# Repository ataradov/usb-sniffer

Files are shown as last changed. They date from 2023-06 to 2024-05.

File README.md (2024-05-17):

# Low-cost USB Sniffer (LS/FS/HS) with Wireshark interface

This sniffer can be used standalone from a command line or as a plugin for
[Wireshark](https://www.wireshark.org/) with direct control from the UI.

Either way, the capture is saved in a standard [PcapNG](https://pcapng.com/) format.

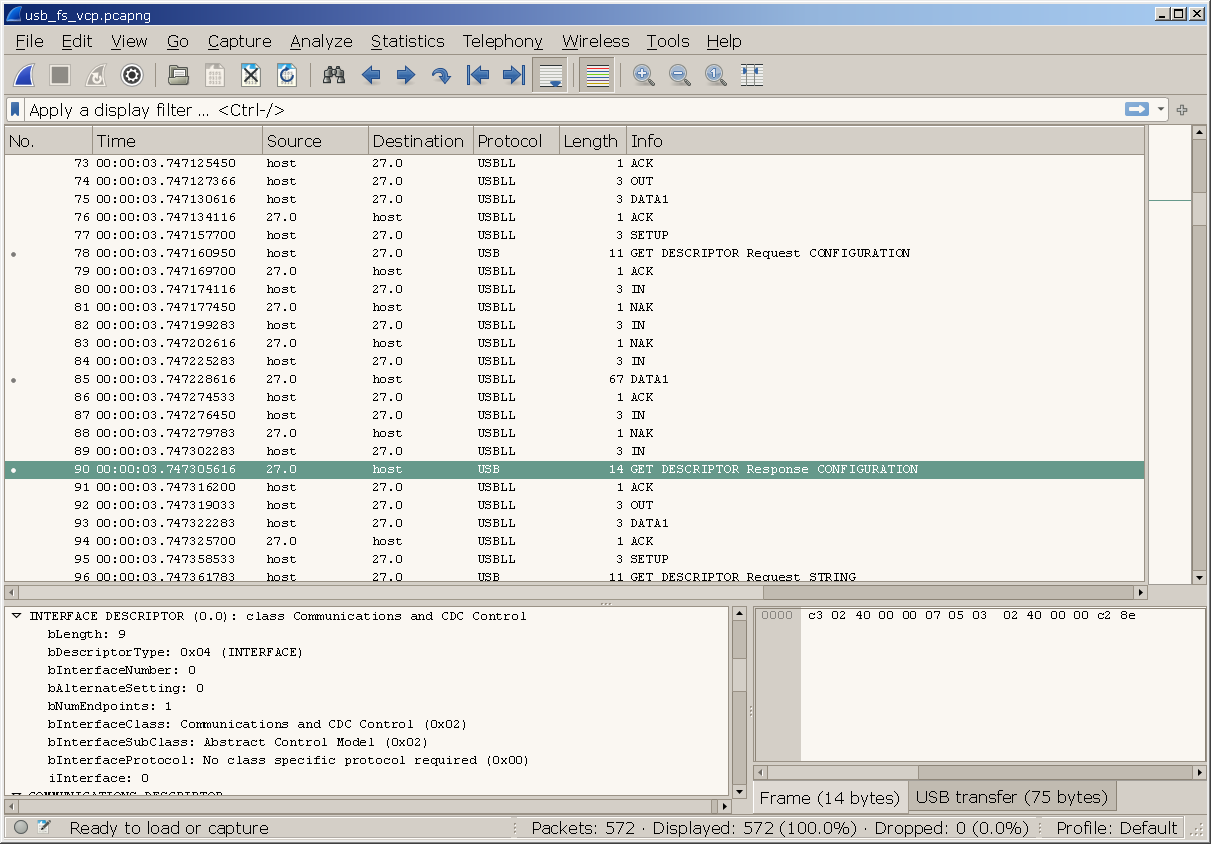
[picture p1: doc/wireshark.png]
Wireshark UI


Here are some example capture files:

 * [Mouse (Low-Speed)](doc/usb_ls_mouse.pcapng)
 * [Virtual COM-Port Adapter (Full-Speed)](doc/usb_fs_vcp.pcapng)
 * [USB Flash Drive (High-Speed)](doc/usb_hs_flash_drive.pcapng)

Note: You will need a recent version of Wireshark (v4.x.x). Older versions may
not be able to decode USB payload, but should still show the raw data.

## Hardware

The sniffer is based around Cypress CY7C68013A MCU, Lattice LCMXO2 FPGA, and
Microchip USB3343 USB PHY.

Prices and availability of ICs vary, but the total BOM should be less than $50.

LCMXO2-2000HC speed grades 5 and 6 were tested and the provided JED file was built
for the speed grade 5, so it should work for both. Speed grade 4 is too slow and
does not meet timing requirements.

Caution: Do not buy CY7C68013A from eBay or AliExpress, they all are either fake
or sketchy in some way. This IC can be quite expensive from regular suppliers,
but [LCSC](https://www.lcsc.com/) is a legitimate supplier and they often have
it at much cheaper prices.

PCBs can be ordered from [OSH Park](https://oshpark.com/shared_projects/avWPFMNs)
or any other PCB manufacturer, [gerber files](bin/usb-sniffer-gerbers.zip) are provided.

There are also STL files for the case.

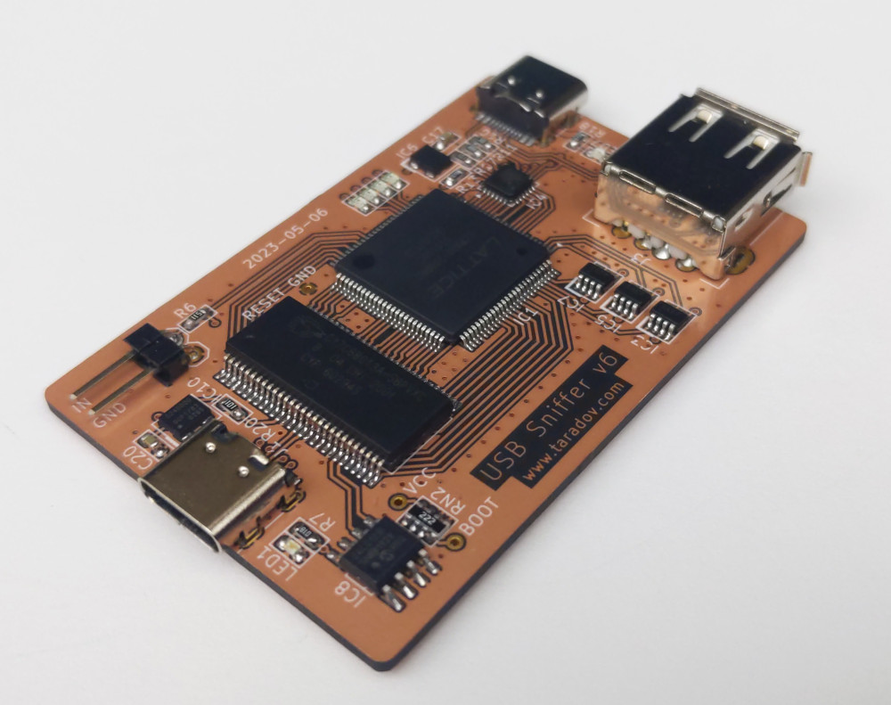
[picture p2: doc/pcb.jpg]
Bare PCB
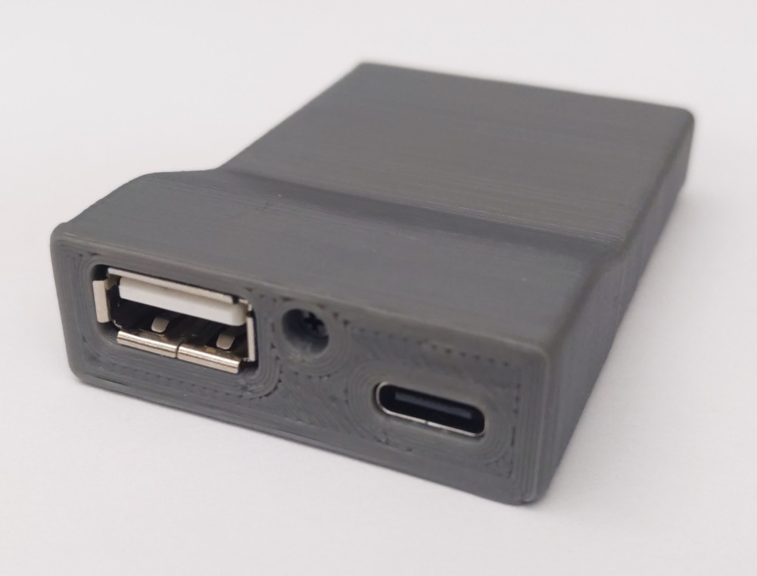
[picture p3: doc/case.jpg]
3D Printed Case
 

## Hardware bring up

This hardware does not require external programmers, both MCU and FPGA are programmed
using a USB interface.

When a board with a blank EEPROM is connected, it would enumerate as an unconfigured
FX2LP device.

Note: on Windows blank FX2LP will enumerate as an unknown USB device. Use supplied
dummy [INF file](bin/blank_fx2lp.inf) as a driver. It will associate blank FX2LP device
with a generic WinUSB driver, so it would be recognized by the tools. Once the firmware
runs, it would supply necessary descripptors automatically.

Note: on Linux copy [90-usb-sniffer.rules](bin/90-usb-sniffer.rules) to /etc/udev/rules.d
to set the permissions to access the device under a regular user.

The first step is to load the firmware into the MCU SRAM:
```
./usb_sniffer --mcu-sram usb_sniffer.bin
```

The device would reset and enumerate as a USB Sniffer with a dummy serial number. After that,
program the EEPROM:
```
./usb_sniffer --mcu-eeprom usb_sniffer.bin
```

After resetting or power cycling, the device would enumerate as a USB Sniffer with a
real serial number. The serial number is derived from the FPGA unique identifier,
so if this step succeeds, it means that FPGA is also functional.

After that program the FPGA flash:
```
./usb_sniffer --fpga-flash usb_sniffer_impl.jed
```

MCU EEPROM can be reprogrammed at any time as long as it is running valid firmware.

In case the firmware gets corrupted, it is possible to run the MCU in the unconfigured
mode by shorting BOOT and VCC test points (located near the EEPROM IC on the board) and
resetting the device. You would need to repeat both steps for programming the MCU
firmware to recover it to the working state.

The functionality and performance of the MCU and FPGA connection can be tested using
the following command:
```
./usb_sniffer --test
```
You should be getting 40-50 MB/s. If the speed is significantly slower, connect the
sniffer directly into the root USB port without intermediate hubs.

It is a good idea to run this test after significant changes to the hardware setup.

## Installation

Pre-built binaries are provided for [Linux](bin/usb_sniffer_linux) and
[Windows](bin/usb_sniffer_win.exe).

To use with Wireshark, copy the file into the extcap plugin directory. Typical
locations are `~/.local/lib/wireshark/extcap` on Linux, and
`C:/Users/<user>/AppData/Roaming/Wireshark/extcap/` on Windows. The exact location is
provided in the `Help -> About Wireshark -> Folders -> Personal Extcap path`.

For Linux, make sure that the binary file has an executable attribute set.

## Usage

After installation, refresh the list of interfaces in Wireshark and you should see
"USB Sniffer" as one of the interfaces:

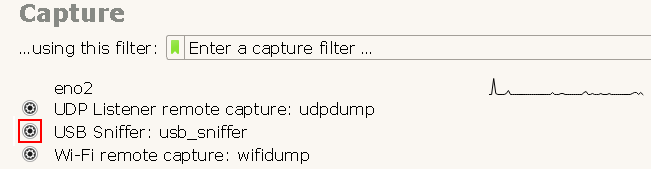
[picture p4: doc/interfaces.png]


The settings icon next to the interface name (highlighted in red) will bring up
the settings dialog:

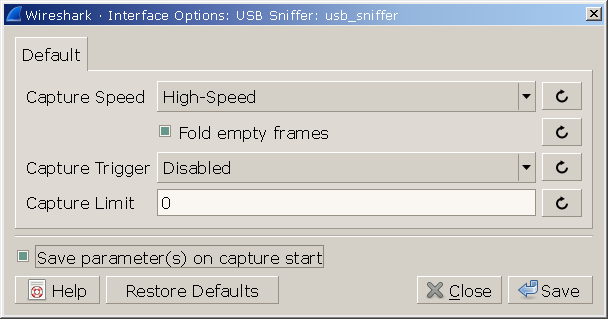
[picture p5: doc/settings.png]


Here you can configure the capture speed, empty frame folding, trigger type and limit
the number of the captured packets (0 for unlimited).

After interface is configured, start and stop the capture as with any other interface.

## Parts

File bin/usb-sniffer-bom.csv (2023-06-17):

Date: | Fri 16 Jun 2023 04:58:26 PM PDT
Tool: | Eeschema 7.0.5-4d25ed1034~172~ubuntu22.04.1
Generator: | /usr/share/kicad/plugins/bom_csv_grouped_by_value.py
Component Count: | 87
Collated Components:
Item | Qty | Reference(s) | Value | LibPart | Footprint | Datasheet | DNP
1 | 24 | C1, C2, C3, C4, C5, C6, C7, C8, C11, C12, C13, C16, C17, C18, C19, C20, C22, C23, C24, C25, C26, C27, C28, C29 | 100nF | ataradov_rlc:C | ataradov_smd:0603
2 | 2 | C9, C10 | 1uF | ataradov_rlc:C | ataradov_smd:0603
3 | 4 | C14, C15, C30, C31 | 2.2uF | ataradov_rlc:C | ataradov_smd:0603
4 | 1 | C21 | 10uF | ataradov_rlc:C | ataradov_smd:0603
5 | 1 | D1 | BAT54S | ataradov_semi:BAT54S | ataradov_ic:SOT-23
6 | 1 | IC1 | LCMXO2-2000HC-5TG100 | ataradov_pld:LCMXO2-100 | ataradov_ic:TQFP-100-0.5mm
7 | 1 | IC2 | MIC5504-3.3v | ataradov_vreg:MIC5504 | ataradov_ic:SOT-23-5
8 | 3 | IC3, IC5, IC7 | MAX9032AKA+T | ataradov_ic:Comp-Dual | ataradov_ic:SOT-23-8
9 | 1 | IC4 | USB3343 | ataradov_ic:USB3343 | ataradov_ic:QFN-24-0.5mm
10 | 1 | IC6 | DSC6101CI2A-026.0000 | ataradov_crystal:DSC61XX-MHz | ataradov_ic:CDFN-4-3.2x2.5mm
11 | 1 | IC8 | 24LC128 | ataradov_ic:I2C-EEPROM | ataradov_ic:SO-8
12 | 1 | IC9 | CY7C68013A-56PVXC | ataradov_mcu:CY7C68013A-56PVXC | ataradov_ic:SSOP-56-0.635mm
13 | 1 | IC10 | DSC6101CI2A-024.0000 | ataradov_crystal:DSC61XX-MHz | ataradov_ic:CDFN-4-3.2x2.5mm
14 | 2 | J1, J2 | USB-C | ataradov_conn:USB-C | ataradov_conn:USB-C
15 | 1 | J3 | USB-A | ataradov_conn:USB-A | ataradov_conn:USB-A-Slots
16 | 1 | J4 | IN | ataradov_conn:Conn-Single | ataradov_conn:Pin-2.54mm
17 | 1 | J5 | GND | ataradov_conn:Conn-Single | ataradov_conn:Pin-2.54mm
18 | 1 | LED1 | Green | ataradov_led:LED | ataradov_smd:0603
19 | 4 | LED2, LED3, LED4, LED5 | Orange | ataradov_led:LED | ataradov_smd:0603
20 | 1 | LED7 | Yellow | ataradov_led:LED | ataradov_smd:0603
21 | 1 | Logo1 | Logo | ataradov_misc:Logo | ataradov_misc:Logo-Small
22 | 4 | R1, R2, R4, R5 | 5.1K | ataradov_rlc:R | ataradov_smd:0603
23 | 7 | R3, R7, R12, R13, R18, R19, R21 | 10K | ataradov_rlc:R | ataradov_smd:0603
24 | 1 | R6 | 510 | ataradov_rlc:R | ataradov_smd:0603
25 | 1 | R10 | 20K | ataradov_rlc:R | ataradov_smd:0603
26 | 1 | R11 | 8.06K | ataradov_rlc:R | ataradov_smd:0603
27 | 1 | R14 | 33K | ataradov_rlc:R | ataradov_smd:0603
28 | 2 | R15, R16 | 4.7K | ataradov_rlc:R | ataradov_smd:0603
29 | 2 | R17, R20 | 100 | ataradov_rlc:R | ataradov_smd:0603
30 | 2 | RN1, RN2 | 2.2K | ataradov_rlc:RN-4 | ataradov_smd:0603x4
31 | 8 | TP1, TP2, TP3, TP4, TP5, TP6, TP7, TP8 |  | ataradov_misc:TestPoint | ataradov_misc:TestPoint-1.27mm-Small
32 | 1 | TP9 | VCC | ataradov_misc:TestPoint | ataradov_misc:TestPoint-1.27mm
33 | 1 | TP10 | BOOT | ataradov_misc:TestPoint | ataradov_misc:TestPoint-1.27mm
34 | 1 | TP11 | RESET | ataradov_misc:TestPoint | ataradov_misc:TestPoint-1.27mm
35 | 1 | TP12 | GND | ataradov_misc:TestPoint | ataradov_misc:TestPoint-1.27mm

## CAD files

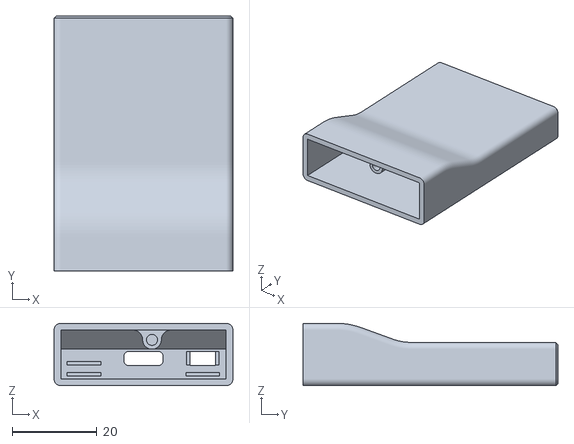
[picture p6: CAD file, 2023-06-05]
hardware/case/usb-sniffer-v6-Case.stl
42.2 x 60.1 x 14.7

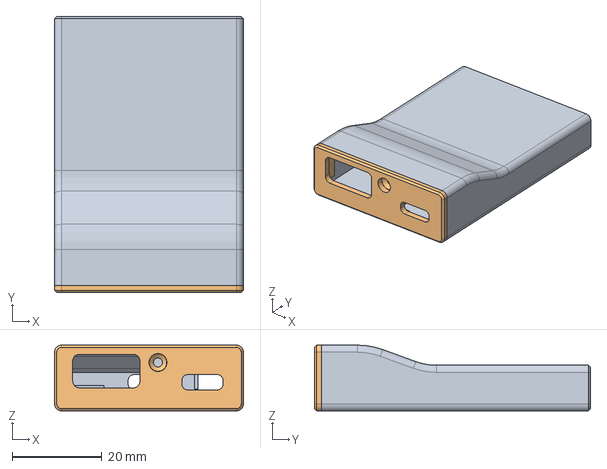
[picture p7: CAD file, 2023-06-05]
hardware/case/usb-sniffer-v6.FCStd
42.2 x 61.7 x 14.7 mm
Case
Cover

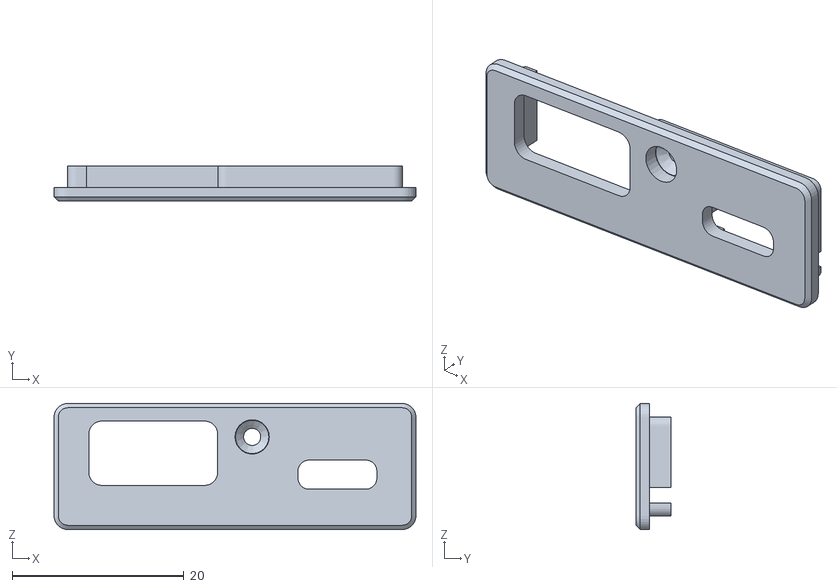
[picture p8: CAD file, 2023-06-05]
hardware/case/usb-sniffer-v6-Cover.stl
42.2 x 4.10 x 14.7

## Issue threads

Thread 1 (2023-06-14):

Request - JLPCB/LCSC BOM & CPL

hanzov69, 2023-06-14:
For the less experienced folks (like myself) out there, would it be possible to provide a BOM & CPL suitable for use with a service like JLCPCB (which is integrated with LCSC and EasyEDA)?

ataradov, 2023-06-14:
Creating BOM should not be that hard, but none of the components have pick points defined. I think most of them are just in the geometric center of the part. LCSC also seems to have most of the major parts. They don't have comparators (well, they have 2 in stock).

I have never ordered board assembly so, I don't know what the requirements are. And I would not be comfortable publishing something I did not test myself. If someone creates the necessary files and tests the whole process with JlcPcb, I can add them to the repo for others to use.

ataradov, 2023-06-14:
But also, if they only assemble boards from EasyEDA and not just random boards, then I don't think there is much we can do. I'm not going to redo the design in EasyEDA for sure.

hanzov69, 2023-06-15:
> I would not be comfortable publishing something I did not test myself
Totally respect that!

> I'm not going to redo the design in EasyEDA for sure.
Naturally. They support pulling in gerber files, so that's not a requirement at all.

EasyEDA/JLCPCB/LCSC are all the same company, so they have an "integrated vertical" type pipeline, but you're not limited to doing it that way. JLCPCB will spin the board just fine with what you've provided, it's only if you want to do assembly with them that you'll need a bom/cpl.

I spent some time after opening this issue, using this plugin ( https://github.com/Bouni/kicad-jlcpcb-tools ) with KiCad I was able to _mostly_ generate a BOM/Placement file for JLCPCB. Biggest thing I ran in to is my own limited knowledge- Looks like LCSC has zero availability on some components and I'm not well enough versed to know what component alternatives (if any) I can use.

I may update the footprints with the exact LCSC part #'s to help along others going down this rabbit hole. If I get something suitable for doing assembly with JLCPCB (and/or EasyEDA formatted), I'll fork the repo and ping (since I respect not wanting to include things you haven't tested).
Thanks for the response!

ataradov, 2023-06-15:
What components are not available? I can help with equivalents. I checked all the major ICs and they were available (although FPGA is much more expensive than on mouser). The only non-generic thing that is not available are comparators. They only had two.

For the clock generators, anything of the specified frequency would work, they don't have to be Microchip parts.

The rest are generic components.

If someone wants to go though the JlcPcb ordering process and test the result, I'm available for help. I'd like people to be able to get the hardware, I just don't have the bandwidth  to do that myself.

sugoku, 2023-06-16:
Hello, I just went through the JLCPCB process myself after finding this and the only things I wouldn't be able to get are the 512 ohm resistor (unless it's supposed to be 5.1K) and the USB3343 (which is out of stock, currently). The USB3343 can be sourced from LCSC but I would have to solder it myself. Also, is there a required size for the EEPROM? I chose a 64Kbit chip.

ataradov, 2023-06-16:
512 Ohm is supposed to be 510 - a very common value. The value of this resistor does not matter, it just provides the current limiting for the trigger input. Anything in the range 0-5 kOhm would work.

64 kBit would work, but I updated the schematic this morning to show 24LC128 - the maximum that can be supported.

Clockwork-Muse, 2024-03-06:
@hanzov69 - Hey, do you have a sample/starting file you can share?  I'm looking at maybe ordering some as well.

Closed 2023-06-15.

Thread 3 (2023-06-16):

IC8 I2C-EEPROM Part Number?

huajijam, 2023-06-16:
Not found in readme and sch

huajijam, 2023-06-16:
found in https://github.com/ataradov/usb-sniffer/discussions/2

using 24lc128 for mine now

ataradov, 2023-06-16:
I've updated the schematic with the EEPROM part name and a full part name for the FPGA.
I've also added note that FPGA speed grade 4 will not work, as it is too slow.

Closed 2023-06-16.

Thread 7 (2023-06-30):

[hardware]IC Obsolete

huajijam, 2023-06-30:
DSC6101CI2A series OSC labled Obsolete in Digikey
and IC6,IC10 are using them
IC6 using 26Mhz only have few stock in Digikey
and the 24Mhz one currently have no stock in Digikey and Mouser

any replacement?I am currently using YXC's OSC and get some problem
in HS device,the sniffer can only detect as FS,and get a lot of error
but with `./usb_sniffer --test` I can get 44-45M/s

huajijam, 2023-06-30:
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

24Mhz: [OT322524MJBA4SL](https://www.lcsc.com/product-detail/Oscillators_Yangxing-Tech-OT322524MJBA4SL_C717686.html) from YXC
26Mhz: ramdom Aliexpress seller claim from YXC [SG-310](https://www.yxc.hk/uploadfiles/2021/11/SG-310.pdf) series and I just not trust it

I bought a new 26Mhz one from Digikey's stock,but it need about 2 week to get in hand,and I just no idea why it can't detect HS mode

huajijam, 2023-06-30:
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

OSC and usb-phy chip image on my board(sry for oversharp img by my phone)

ataradov, 2023-06-30:
Just to double check - have you configured HS mode in the settings? There is autodetection of the speed, but it is mostly for logging and information use. There is no automatic switch. You need to go into the interface settings and configure the speed you expect to see.

I've used 12 MHz version of that Yangxing Tech oscillator from LCSC in a different project and had no issues with them. But I would not trust AliExpress one, especially if there are issues.

huajijam, 2023-06-30:
>

how 2 set speed? in Wireshark? I can't found it

ataradov, 2023-06-30:
In the list of interfaces there is a cog icon next to the name:
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

huajijam, 2023-06-30:
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
it seems work now, but I am getting this error
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

huajijam, 2023-06-30:
btw,will it cause error when using HS mode to capture LS/FS?
if no,why not HS by default

ataradov, 2023-06-30:
This is the issue on the host side. In the data stream there is a toggling bit for each packet used to detect possible corruption. There are many reasons why this may happens, including overflows, bad cables or hubs on the device side. I would try a different cable and a different USB port on a root hub.

You need to capture with the setting that is actually use by the bus. It will not be able to receive the frames at the incorrect speed. There is no identification, speed is a setting. Normally devices negotiate which speed they want to use, but sniffer in general does not know that.

huajijam, 2023-06-30:
>

> This is the issue on the host side. In the data stream there is a toggling bit for each packet used to detect possible corruption. There are many reasons why this may happens, including overflows, bad cables or hubs on the device side. I would try a different cable and a different USB port on a root hub.
>
> You need to capture with the setting that is actually use by the bus. It will not be able to receive the frames at the incorrect speed. There is no identification, speed is a setting. Normally devices negotiate which speed they want to use, but sniffer in general does not know that.

but this error will cause the capture stop and need manually restart,can there be an option to display as a log insteat of killing the capture?

ataradov, 2023-06-30:
No, decoding of the incoming stream depends on the correct tracking of the state. This is how software knows what is a header and what is a data in a continuous stream. There is no way to recover if there was de-synchronization.

ataradov, 2023-06-30:
Note that this is not an overflow on the capture side, which would cause frames to be dropped and corresponding log message to be issued.

This is an error on the host side, which should not happen really. If it does, it means that host side communication is not reliable for some reason.

If you can't make it work with a different cable and a different USB port, I can add a bit of debug logic and we can try to debug this if you can reliably reproduce the issue. I've only seen it a couple times when working tough a dodgy hub.

huajijam, 2023-06-30:
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

I can reproduce it a lot of time,I make it bcz my desktop usb3.0 hub sometimes will give me a code 43 or code 10 in some usb 2.0 device and only 2.0,I want to check what happened
but it seems like when I plug it in sniffer,it will fix this problem(wtf)
I am currently using hub from my dell monitor, and I can reproduce it by plug in a bad usb device
as ur said, it came from error in host,but I am using a different hub for my target, and it will still error

both desktop hub and monitor hub are plug into pc's back usb3.0

ataradov, 2023-06-30:
I don't understand your setup. But using hubs for the sniffer host connection is prone to cause errors like this. Hubs sometimes are bad at handling a lot of traffic. It is far better to use direct connection for the sniffer itself.

As for fixing the errors - I don't know why that wold be the case. In theory host would not be able to tell if there is a sniffer in-between.

huajijam, 2023-06-30:
> I don't understand your setup. But using hubs for the sniffer host connection is prone to cause errors like this. Hubs sometimes are bad at handling a lot of traffic. It is far better to use direct connection for the sniffer itself.
>
> As for fixing the errors - I don't know why that wold be the case. In theory host would not be able to tell if there is a sniffer in-between.

rear usb3.0 → desktop 3.0hub(have issues) → target type-c port
rear usb3.0 → dell monitor 3.0hub → host type-c port

monitor's hub should be fine, as it will work if the desktop does not

maybe some debugging logic will make it easier to find out where the problem is

ataradov, 2023-06-30:
I will add some logic a bit later, not sure how helpful it would be though.

But in the mean time I would try to avoid hubs for the host connection.

ataradov, 2023-07-01:
I've added printing out of the header along with the error message. This in combination with the last frame should show a bit more information on what is going on. I don't know if that would be sufficient to fully debug this specific case though.

The error window will no longer show up, but the capture would stop on errors like this. The last messages in the log would be the diagnostic info.

Closed 2023-07-01.

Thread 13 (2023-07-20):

I used 4TG100C, Transfer rate:  0.00 MB/s

vgegok, 2023-07-20:
I used diamonds to regenerate the jet file of 4TG100C, and initially everything was normal. However, when I tried to measure the speed, I got a result of 0 on Windows, and Linux would directly report an error.

# Windows:

```
PS E:\USB\usb-sniffer-main\usb-sniffer-main\bin> .\usb_sniffer_win.exe --mcu-sram .\usb_sniffer.bin
Uploading 3187 bytes into the FX2LP SRAM
...done

PS E:\USB\usb-sniffer-main\usb-sniffer-main\bin> .\usb_sniffer_win.exe --mcu-eeprom .\usb_sniffer.bin
Programming 3187 bytes into the FX2LP EEPROM (SN: 443602XXXXXXXX)
...done

PS E:\USB\usb-sniffer-main\usb-sniffer-main\bin> .\usb_sniffer_win.exe --fpga-flash ..\fpga\impl\usb_sniffer_impl.jed
Programming FPGA flash
Erasing flash
Programming configuration data .....
Verifying configuration data
Programming and verifying Feature Row
Programming and verifying FEABITS
Exiting programming mode
...done

PS E:\USB\usb-sniffer-main\usb-sniffer-main\bin> .\usb_sniffer_win.exe --test
Starting speed test
Transfer rate:  0.00 MB/s
Transfer rate:  0.00 MB/s
Transfer rate:  0.00 MB/s
Transfer rate:  0.00 MB/s
Transfer rate:  0.00 MB/s
Transfer rate:  0.00 MB/s
Transfer rate:  0.00 MB/s
Transfer rate:  0.00 MB/s
Transfer rate:  0.00 MB/s
Transfer rate:  0.00 MB/s
```

# Ubuntu 20.04:

```
$ ./usb_sniffer --test
Starting speed test
Error: usb_capture_callback(): 4
```

ataradov, 2023-07-20:
Callback status 4 is LIBUSB_TRANSFER_STALL. This is strange,because FX2LP should not stall on hardware endpoints. What was the source for the FX2LP device?

From the FPGA side, I would verify that PHY oscillator is running at 26 MHz and that there is 60 MHz clock on the output from the PHY.

Speed grade 4 device does not meet timing requirements, so you should see warnings about that in the log. It might work at room temperature, I guess.

vgegok, 2023-07-20:
Your answer gave me a hint, I know why. Since the 8.06K resistor has not yet arrived, I did not weld it!

I haven't read your code carefully yet.
At first, I didn't know which clock source the FPGA uses. I thought that the USB3343 wouldn't affect speed testing if it didn't work.
Now I know that the FPGA clock is provided by USB3343 (60MHz), so when conducting speed testing, the 8.06K resistor must be soldered.
Looking forward to receiving it!

Thank you again for your answer!

---- Replied Message ----
| From | Alex ***@***.***> |
| Date | 07/20/2023 23:12 |
| To | ataradov/usb-sniffer ***@***.***> |
| Cc | vgegok ***@***.***>,
Author ***@***.***> |
| Subject | Re: [ataradov/usb-sniffer] I used 4TG100C, Transfer rate: 0.00 MB/s (Issue #13) |

Callback status 4 is LIBUSB_TRANSFER_STALL. This is strange,because FX2LP should not stall on hardware endpoints. What was the source for the FX2LP device?

From the FPGA side, I would verify that PHY oscillator is running at 26 MHz and that there is 60 MHz clock on the output from the PHY.

Speed grade 4 device does not meet timing requirements, so you should see warnings about that in the log. It might work at room temperature, I guess.

—
Reply to this email directly, view it on GitHub, or unsubscribe.
You are receiving this because you authored the thread.Message ID: ***@***.***>

vgegok, 2023-07-21:
I soldered an 8.2K resistor at position R11, and now the test is working properly!

At first, I tested the clock signals of 26MHz (PIN21) and 60MHz (PIN2) with an oscilloscope and found that 26MHz was normal, but there was no 60MHz clock. After I welded the resistor, everything was normal.

As I said, this bias resistor will affect the operation of USB3343, resulting in the inability to output a 60MHz clock signal.

```
 .\usb_sniffer_win.exe --test
Starting speed test
Transfer rate: 48.57 MB/s
Transfer rate: 48.96 MB/s
Transfer rate: 48.71 MB/s
Transfer rate: 48.81 MB/s
Transfer rate: 48.86 MB/s
Transfer rate: 48.81 MB/s
Transfer rate: 48.81 MB/s
Transfer rate: 48.81 MB/s
Transfer rate: 48.81 MB/s
Transfer rate: 48.76 MB/s
Transfer rate: 48.86 MB/s
Transfer rate: 48.91 MB/s
Transfer rate: 48.71 MB/s
Transfer rate: 48.81 MB/s
Transfer rate: 48.81 MB/s
Transfer rate: 48.76 MB/s
Transfer rate: 48.91 MB/s
Transfer rate: 48.76 MB/s
Transfer rate: 48.96 MB/s
Transfer rate: 48.76 MB/s
Transfer rate: 48.86 MB/s
Transfer rate: 48.86 MB/s
Transfer rate: 48.76 MB/s
Transfer rate: 48.81 MB/s
Transfer rate: 48.76 MB/s
Transfer rate: 48.86 MB/s
Transfer rate: 48.81 MB/s
Transfer rate: 48.91 MB/s
Transfer rate: 48.91 MB/s
Transfer rate: 48.67 MB/s
Transfer rate: 48.86 MB/s
Transfer rate: 48.76 MB/s
Transfer rate: 48.86 MB/s
Transfer rate: 48.76 MB/s
Transfer rate: 48.86 MB/s
Transfer rate: 48.81 MB/s
Transfer rate: 48.81 MB/s
Transfer rate: 48.86 MB/s
Transfer rate: 48.91 MB/s
Transfer rate: 48.81 MB/s
Transfer rate: 48.91 MB/s
Transfer rate: 48.86 MB/s
Transfer rate: 48.76 MB/s
Transfer rate: 48.86 MB/s
Transfer rate: 48.81 MB/s
Transfer rate: 48.86 MB/s
Transfer rate: 48.96 MB/s
Transfer rate: 48.71 MB/s
Transfer rate: 48.91 MB/s
Transfer rate: 48.91 MB/s
Transfer rate: 48.67 MB/s
Transfer rate: 48.91 MB/s
Transfer rate: 48.81 MB/s
Transfer rate: 48.96 MB/s
Transfer rate: 48.71 MB/s
Transfer rate: 48.91 MB/s
Transfer rate: 48.81 MB/s
Transfer rate: 48.86 MB/s
Transfer rate: 48.91 MB/s
Transfer rate: 48.76 MB/s
Transfer rate: 48.91 MB/s
Transfer rate: 48.81 MB/s
Transfer rate: 48.86 MB/s
Transfer rate: 48.81 MB/s
Transfer rate: 48.76 MB/s
Transfer rate: 48.67 MB/s
Transfer rate: 48.76 MB/s
Transfer rate: 48.81 MB/s
Transfer rate: 48.62 MB/s
Transfer rate: 48.71 MB/s
Transfer rate: 48.81 MB/s
Transfer rate: 48.62 MB/s
Transfer rate: 48.71 MB/s
```

vgegok, 2023-07-21:
@ataradov, Thank you.
I will close this issues.

ataradov, 2023-07-21:
Good to know that it actually does not even start without that resistor.

Closed 2023-07-21.

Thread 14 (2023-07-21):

Error: libusb_bulk_transfer(): LIBUSB_ERROR_OVERFLOW, usb_capture_callback(): 6

croofec, 2023-07-21:
I can't run a speed test after successfully installing. The connection between the USB and the computer works fine, I can't sniff
Current usblib version: libusb-1.0.26, all parts from mouser.

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

Hardware or software issue?

ataradov, 2023-07-21:
This may be related to a recent change.

Build the binary from the source and change TRANSFER_COUNT in usb.c from 16 to 8 or even 4.

If this helps, please check what is the maximum value that causes the issue.

I'm not sure what defines how many transfers libusb would accept at the time. It appears to be system dependent.

croofec, 2023-07-24:
Changing the parameter had no effect even when I set it to 1.  I started debugging the software and always the bulk transfer buffer returned the size of 64 which is smaller than the size of 512. This could not cause overflow.  But in the dmesg:

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

I changed the slot from USB2.0 to USB3.0 and it works :D

ataradov, 2023-07-24:
Ok, yes, I don't do anything to accommodate the case when it enumerates as a Full-Speed device.

HS mode is USB 2.0, so there must be something wrong with that specific port or your cables. It looks like it tried to enumerate as HS device, but could not.

Closed 2023-07-24.

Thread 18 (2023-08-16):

Only syslog entries

brunopp, 2023-08-16:
I just assembled the board and followed the instructions to flash the device and get the desired speed of 40-50 MB/s - all good.

When connecting a usb device (mouse -> full speed) to the port I get data in wireshark, but no usb data, I only get "Syslog" entries. I have also tried different usb drives at high speed. Also the log stops after about about 1000 entries (only for high speed). I have selected the correct Capture Speed in wireshark.

All the devices I have tried works when connected through the usb-sniffer board.

I have also noticed I get VBUS OFF in one of the first entries as opposed to VBUS ON the examples under /doc.

Logs: [wireshark.zip](https://github.com/ataradov/usb-sniffer/files/12356815/wireshark.zip)

Also only two LED's light up (LED 1 and LED 7), are the other LED supposed to light up?

As for the BOM I could not find the exact oscillators, but found others within 50 ppm:
[DSC1001CI2-024.0000](https://www.mouser.dk/ProductDetail/998-1001CI2-024.0000)
[DSC1001CI5-026.0000](https://www.mouser.dk/ProductDetail/998-1001CI5-026.0000)

ataradov, 2023-08-16:
This looks like there is some issue with the USB PHY.

First of all, check that the soldering looks ok. Attach magnified pictures, if you can.

Then check that you have 26 MHz on the output of the oscillator and 60 MHz on the output of the PHY (CLKOUT pin).

If you look at the HS log, you will see a lot of JK toggles, which start with "[singel]" and continue with "[both]". This is a normal part of the HS speed negotiation. What is wrong here is that they are supposed to be ~50 us in duration and in your case they are 20 us. This looks like incorrect clock is being used.

ataradov, 2023-08-16:
And LEDs are fine, the 4 other LEDs are there for debugging and are not used in the release version.

brunopp, 2023-08-16:
The oscillator (IC6) is outputting 26 MHz. But I'm not getting 60 MHz on the USB (IC4) on pin 2, but 26 MHz as well as shown below:

[Circuit](https://github.com/ataradov/usb-sniffer/assets/6736551/7c2ae64c-b328-4abf-bd88-24536002b0bd)
[Oscilloscope (IC4, pin 2)](https://github.com/ataradov/usb-sniffer/assets/6736551/7dd35c75-c68a-4e8f-8072-c623b71c555f)

Which is odd? The according to the [datasheet](https://eu.mouser.com/ProductDetail/Microchip-Technology/USB3343-CP-TR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) it should output 60 MHz.

ataradov, 2023-08-16:
What is the value of the resistor on the pin 19 (RBIAS). It is critical that it is 8.06 kOhm +/-5%.

Neither B22 or 822 seem to match that value, but SMD codes are all over the place. So check the value with a multimeter.

brunopp, 2023-08-16:
It isn't clear how important exact values are from the BOM, so I just used the closest I had 8.2kOhm +-1%. I tried to solder 470k in parallel with 8.02k getting 8.06k measured (isolated from the circuit), but no luck.

Are there other critical resistor values in the circuit?

ataradov, 2023-08-16:
If the value is specified with that accuracy, it must be important. If 8.2 kOhm worked, it would have been on the schematic, it is not like I'm adding random values for fun.

No other values are critical as far as I know, so I would look for possible shorts.

Or may be reflow or change the PHY and see if that helps. I have never seen it output the input clock directly. Usually it is either nothing if the resistor is missing entirely, or 60 MHz.

ataradov, 2023-08-16:
And check for other voltages too, like VDD18 should be at 1.8 as supplied by the internal voltage regulator. If it is not at 1.8, check that C15 is placed and has correct value.

ataradov, 2023-08-16:
The JK chirp at the beginning still looks messy. It was way better in your original capture. It should be clean J/K toggles at ~50 us internal.

Double check your resistor divider ladder for the compactors.

brunopp, 2023-08-16:
Strange, I didn't reflow the backside where the resistor dividers are placed nor the comparators on the top side.

ataradov, 2023-08-16:
It feels like something is not soldered fully. There should be no random line state changes in the middle of the data.

I would carefully check all the comparators and related tracks pins. May be measure reference voltage levels on the resistive ladder and make sure that they are correct.

brunopp, 2023-08-16:
You are talking about the high speed log? Specifically: Syslog Line state: undefined? For example line no. 7715 and 8893.

I'll try some additional reflow.

ataradov, 2023-08-16:
Yes. Look at your original HS log. At the beginning you can see that there are K/J state pairs, first [single] and then [both]. Their timing is not correct because it was running at 26 MHz, but the order is fine.

The time in the original log is 21 us, but the actual real time is (60/26) * 21 us = 48.5 us. This is the time you should expect.

You should see the same in the new log. There should not be undefined states. It is fine if there are some due to transient, but they should not be long.

brunopp, 2023-08-16:
Reflowing the comparators and divider resistors seemed to have worked, I find no undefined states (except a little bit at the beginning, which should be due to transient as you mentioned).

Logs: [wireshark - after reflow.zip](https://github.com/ataradov/usb-sniffer/files/12364141/wireshark.-.after.reflow.zip)

ataradov, 2023-08-16:
Yep, this is the correct result.

Closed 2023-08-16.

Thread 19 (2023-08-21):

Issue with high speed devices

bkerler, 2023-08-21:
Hi,

I've built two boards and both works fine with low-speed and full-speed devices. However if I try to connect any high-speed device such as a android smartphone, the device cannot be enumerated (neither adb, fastboot nor serial). I checked the oscillators and they deliver 24 mhz and 26 mhz as expected, 60 mhz at the usb_clk of the usb3343. Voltage measured at vdd18 is 1.78V. Doesn't matter if the capture is on or not, the usb enumeration fails all the time and the device isn't detected.

Any ideas why the usb enumeration fails ?

[usblog.zip](https://github.com/ataradov/usb-sniffer/files/12402017/usblog.zip)

ataradov, 2023-08-21:
Try different USB port on the PC and don't use hubs for the target device. Also make sure that the board are clean from flux contamination. Some fluxes are mildly conductive and may cause issues at high frequencies.

 The logs looks similar to another issue and there the problem was resolved by using a different USB port.

Also, just for statistics, what PC/motherboard you are using?

bkerler, 2023-08-21:
Ok, it seems I've figured out what the issue is on high speed.

SW-Side:
1. Capture has to run, otherwise fails as well
2. Always connect the device port first (USB-A), then the sniffer port (USB-C), otherwise it fails.

HW-Side:
On the host side (host -> sniffer) anything (usb 2.0/usb 3.0/usb 3.1) except usb 4.0 hub works.
On the client side (sniffer -> host) only usb 2.0 hub works (here: Realtek Semiconductor Corp. RTS5411 Hub)

I've tested it on two amd systems (usb 3.1 regular pc and usb 4.0 laptop lenovo z16).

So I'm still wondering if the usb3343 doesn't like amd hubs or if it's an issue with the two boards that I've got (both were fully pnp by jlcpcb except the usb3343). On the optical side using microscope I couldn't see any potential issue.

bkerler, 2023-08-21:
Could it be that the cc1 and cc2 lines might cause issues ?

ataradov, 2023-08-21:
Capture running or not is a purely logical thing, it does not affect the transceiver state, so it should not matter.
Order of device connection also should not matter. Something is just marginal in that setup.

It is better to avoid hubs for performance reasons, especially for the sniffer itself. Hubs decrease available bandwidth quite a bit. What does speed test say, BTW?

A sniffer has to break the signal lines in order to tap into them, so there will be some loss of integrity, plus transceiver and comparators  add extra load. Even if not significant, it is not zero, which may push marginal configurations into unstable mode.

It is strange to me that in your logs transceiver can't receive any frames at all, even broken ones. So, something breaks to the point where even sync sequence is damaged.

How would CCx lines cause the issue? The sniffer has required resistors on the USB-C side. In that respect electrically it is no different than any Type-C to Type-A cable.

bkerler, 2023-08-21:
No, cc1 and cc2 can be ruled out as both usb-c are connected via the same resistors. So seems clearly the usb3343 or IC6 is causing the issues. I had to replace the IC6 with this chip : [3N26000G33YC](https://jlcpcb.com/partdetail/247517-3N26000G33YC/C252342), just to rule that out, could this one cause the issues ?

ataradov, 2023-08-21:
Although no, there are SOF and Get Device Descriptor requests from the host. The device does not respond, so it is not the sniffer that can't see the frames. You can see the host retries many times before giving up. So, it also can't see them. It is Android phone that can't seemingly interpret them after whatever minor loss is introduced by the sniffer.

Try with different devices, including simple stuff like USB flash drives. This may be just Android phone issue and it being marginal.

+/- 30 ppm generator should be good enough.

bkerler, 2023-08-21:
Tried with several high speed devices including usb sticks, they all seem to have the same issues on enumeration, only a specific hub setup (usb 2.0 on the device side) does work. Without the sniffer (or with beagle480 sniffer instead), everything seems to work fine, so it has to be something the sniffer introduces. I saw that the issue #7 seems to have had the same problems.

Speed test says 44.90 MB/s.

bkerler, 2023-08-21:
Seems the issue is the usb3343, found an answer in a forum :
[errata](http://ww1.microchip.com/downloads/en/DeviceDoc/80000645A.pdf)

[forum_message](https://community.st.com/t5/embedded-software-mcus/stm32f2-f4-problems-with-various-ulpi-usb-phys/m-p/554240)

ataradov, 2023-08-21:
I have no idea what it could be. I doubt it is the transceiver. If anything, it would be the comparators.

I have not done significant testing with hubs, since the plan was always to connect as close to the root hub as possible.

This errata has nothing to do with this, since PHY here is fully passive. The whole sniffing tap should not introduce significant distortion between the devices.

The most likely issue is signal integrity caused by discontinuity in the path and multiple taps going the comparators and the transceiver.

bkerler, 2023-08-21:
Ok, will try to remove the comparators then and retest the behavior.

ataradov, 2023-08-21:
Also, RTS5411 sees to support USB3.2 Gen1, so it is not just UBS2.0 hub. And in either case, none of them should care, since we are clearly only using USB2.0 part.

ataradov, 2023-08-21:
Another possible factor - the cables. I just tried to experiment with hubs. The only type of hubs I have is this https://www.amazon.com/gp/product/B00JX1ZS5O .  I chained two of them just to add extra challenge.

I used Pixel 3a as a target to get as close to your setup as possible.

With the first test I used one good USB cable and one random Chinese (with silicone cable, so super flexible). With that setup I had all sorts of issues. Not missing packets entirely, but CRC issues and random packet drops, device failed to connect half the time.

I replaced the Chinese cable with a good one and all issues went away, it works perfectly every time though both hubs.

The "good" cables I use are  https://www.amazon.com/gp/product/B01GGKYR2O/ , which perform very well.

For the flexible cables - I suspected they are not the best, but I really like how flexible they are. And with that cable and direct connection (no sniffer), the phone also works.

So, obviously sniffer adds some distortion, which is to be expected. But it only affects the result with bad USB cables. The same setup with a cable swapped works just fine.

ataradov, 2023-08-21:
And this is something to keep in mind too - with the sniffer you have double the cable length. Even if the sniffer is ideal and does not cause additional distortion, increasing the cable length may cause issues on its own.

wocard2, 2023-08-29:
Could adding one (or two) TUSB216 or TUSB217 to the design help with bad and/or long cables?

ataradov, 2023-08-29:
Impossible to tell without having proper measurement equipment and understanding what any of the issues are. And I don't have such equipment.

I don't consider it to be a serious issue. Using good cables is a good idea no matter what.

bkerler, 2023-11-26:
I did more tests and it seems that the sniffer works with android phones with microusb pretty well but has issues with smartphones  with usb-c port (even though these only have usb 2 in fact). So far no difference with the comparators removed / replaced

LiHangBing, 2025-04-17:
I find the same questions,
I use a "Cypress FX2LP No EEPROM Device" device,
first, I connect listen port and device port, and then plug host port to a usb port which belong to the same root hub (each port is usb 2.0), It  emulate fail .

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

then I choose a better cable for host connect, and plug the host cable to annother root hub (usb 3.0), it works!

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

Maybe because of plugging two usb cables to a same hub and it works only at usb2.0 doesn't work.

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

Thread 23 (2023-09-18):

Issue with high speed devices

aozima, 2023-09-18:
Hi,

I've built 5pcs boards, works fine with full-speed devices.

I try to connect any high-speed device, e.g: Udisk or Card Reader。

The PC can enumeration  and  read/write disk, but Wireshark can't capture data.

test hardware

```
$ sudo ./usb_sniffer_linux --test
Starting speed test
Transfer rate: 48.05 MB/s
Transfer rate: 48.26 MB/s
Transfer rate: 48.25 MB/s
Transfer rate: 48.12 MB/s
```

aozima, 2023-09-18:
case 1:
only `Detected speed: Full-Speed`

```
Protocol	Length	 	Info
Syslog	27		USB PHY error
USBLL	1		Invalid Packet ID (0xff)
Syslog	39		Line state: J (583.00 ns)
Syslog	40		Detected speed: Full-Speed
Syslog	41		Line state: SE0 (257.70 us)
Syslog	46		Line state: K [single] (5.08 ms)
Syslog	40		Line state: SE0 (25.35 us)
Syslog	47		Line state: K [single] (49.00 us)
Syslog	47		Line state: J [single] (49.00 us)
```

ataradov, 2023-09-18:
Did you configure the high-speed mode in the interface settings? The detection message is just information, it does not actually change the capture speed.

Closed 2023-09-18.

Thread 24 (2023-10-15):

LCMXO2-2000HC-5TG100C

imayka, 2023-10-15:
Hello. Can I replace LCMXO2-2000HC-5TG100C with LCMXO2-2000HC-5TG100I ? LCSC has both of them but prices are 65$ vs 15$ correspondingly. Should I modify or recompile FPGA project if yes? Thank you!

imayka, 2023-10-15:
Ok, so the difference between Industrial or Commercial is only Operating Temperature. But will firmware prepared for C device work with I device without modification (recompiling)?

ataradov, 2023-10-15:
You can use any temperature variant without changing the binary.

ataradov, 2023-10-15:
For me it shows both out of stock, but industrial is available pre-order, so it has the real updated price. Commercial one still has outrageous shortage price listed.

imayka, 2023-10-15:
> You can use any temperature variant without changing the binary.

Thank you!

Closed 2023-10-15.

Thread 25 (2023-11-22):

The on-board LEDS

fizzyade, 2023-11-22:
It would be useful to have through hole pad options for the on board LEDS, once the PCB is in an enclosure the LED's are no longer visible, I can obviously modify the hardware to provide these PTH holes, it's a 2 minute job, but I figure that it might be a useful thing for other people since an enclosure protects the PCB, so I figured I'd ask here to see if threres any interest in providing these pads in the origin repo.  I could solder coil wire directly to the SMD pads, but my concern there would be that it would be relatively easy to rip the pad off during later disassembly if I forget about it.

The pictures here show my case design, I could put the leds on a surface on the main body or on the end caps.

Many thanks for the brilliant project!

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

ataradov, 2023-11-22:
For this design, I don't really want to do anything with the LEDs. In my case I relied on the gray plastic being transparent, and it works well enough. LEDs here are not all that useful anyway, and I don't want to create a hardware revision just for that.

I hate working with through hole LEDs, so I avoid them in my designs, but since I'm also making 3D printed cases, it does become an issue. And I'm trying to figure out how to address this. But my experiments are focused on making clam shell cases and printing in holes for the light pipes or something like this.

fizzyade, 2023-11-23:
No problem, I figured that since they weren’t there then that would be the answer!  I’ll just modify it myself (thanks for the open source design!)

It wasn’t so much about actually mounting PTH LED’s directly onto the board, it was purely just providing a PTH hole so that the location of the LED's don’t need to be tied to a specific location on the PCB, with a test point the wires could just as easily connect to a daughter board that has a bunch of SMD LED’s arranged is a coherent order.

It’s just a sanity check for me since my USB cables often work themselves loose on my laptop, so looking at the LED’s is an easy confirmation that at least power is getting to the device from the host.

Adrian
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

KarlK90, 2024-02-18:
@fizzyade Hi Adrian, I like your take on the case very much, would you mind sharing the case files?

fizzyade, 2024-02-18:
Yeah no problem, I will upload them later to printables, remind me tomorrow if I haven't replied with the link.

fizzyade, 2024-02-18:
> @fizzyade Hi Adrian, I like your take on the case very much. ~would you mind sharing the case files~? Already found it here https://www.printables.com/model/657228 - thanks for sharing.

Yeah, I couldn't log in earlier and when I just managed to get in I realised I'd already shared it!

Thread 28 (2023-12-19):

USB high speed capture lost some packets

genknife, 2023-12-19:
Hi,
I captured a device like usb printer with high speed. If I print one page with simple content, it is OK. But if I print one page with complex content，some packet lost, And some syslog message said "Hardware buffer overflow".
I have also done a transfer rate test, result is about 48MB/s.
USB 2.0 high speed can mostly reach 60MB/s, but README recommend  transfer rate 40~50MB/s. If printer usb high speed transfer rate reach 60MB/s, I will always lost some packets?

ataradov, 2023-12-19:
Maximum theoretical USB HS transfer rate is ~53 MB/s after physical protocol overhead. But with the way practical host schedule transfers, you get 48-49 MB/s as a maximum practical transfer rate. So, the printer is also not going to be faster than 48 MB/s. But the sniffer is adding its own overhead with timestamp information and other information about the packets, so it will always be slower.

Some lost frames are normal. It is impossible to capture a lot of traffic on one interface going at full speed. This is a debugging tool, it is not meant to capture absolutely everything at once.

That being said, there are a couple things you can check:
1. Do a speed test while printer is printing. See if the speed drops. It may drop depending on the root hub port mapping. You may be able to get better results by using different set of USB ports.
2. This may be a slowness of Wireshark and the pipe interface (it is known to be slow on Windows). You can capture directly to the file from the command line and then open the final captured file in Wireshark. This way you will not be limited by the Wireshark UI trying to display all those frames in run-time.

tencyrat, 2023-12-22:
0x012ba043

tencyrat, 2023-12-22:
Error: incorrect FPGA IDCODE (0x012ba043)
so i should chang fpga.c to 0x012ba043?anything i need to change?

tencyrat, 2023-12-22:
same issues,i replace it with LCMXO2-2000HC-6TG100C,could you offer me 6TG100C jed files?thanks!

tencyrat, 2023-12-22:
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

same issues,i replace it with LCMXO2-2000HC-6TG100C,could you offer me 6TG100C jed files?thanks!

ataradov, 2023-12-22:
Replacing with a different FPGA will not do anything for lost packets. The same JED file will work for all speed grades.

In the deleted comments you mention your ID CODE is 0x012ba043. This ID CODE belongs to LCMXO2-1200HC. This will not work, you need 2000HC device.

tencyrat, 2023-12-23:
First of all, thanks for your reply. I may have bought a fake chip. The silk of the chip is LCMXO2-2000HC-6TG100C.but the ID CODE is 0x012ba043.

ataradov, 2023-12-23:
This is a strange thing to fake, since it will be discovered right away. Those devices have different bit-stream size, so programming would not work even if you change the ID.

Can you show pictures of the device? I have never seen them faked, so I wonder how it compares to the real device.

tencyrat, 2023-12-25:
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

when i patch the id code,fpga burning pass,but it does not work,speed test is 0MB/s.
i use microscope to take photo.5TG is Genuine,6TG is fake.
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
i purchase it from taobao.com so avoid it!

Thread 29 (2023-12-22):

We need adaptive communication speed!

Antecer, 2023-12-22:
My device is compatible with HS and FS communication. It works in HS by default. When the HS handshake fails, it will automatically switch to the FS handshake.
I hope usb-sniffer can work in HS mode by default and be backward compatible with FS communication capture.
If working at a fixed communication speed, it will not meet my work needs in this case.

ataradov, 2023-12-22:
There is no way to automatically switch the speed. First of all, there is no reliable way of doing this. The speed negotiation is a process that can be interpreted one way by the tool and the other way by the devices.

And the more important thing - it is no the goal of this tool. This is a debugging tool that is supposed to be used in a controlled environment.

When debugging a device that is capable of operating at a multiple speeds, debug operation at each speed separately with a host that you know can do HS or FS. This way you know what speed is expected to be negotiated and you can set it up ahead of time.

If you need to understand why the speed detection failed, you can use either speed, since all of that happens with line-state changes, which are the same regardless of the configured speed.

If you can describe a legitimate scenario where this is necessary, I'll be glad to hear it. But I pretty much guarantee that I won't do auto speed switch.

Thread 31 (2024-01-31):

Help flashing to eeprom

anujdeshpande, 2024-01-31:
Hey @ataradov - I am trying to assemble this, but running into issues with the FPGA IDCODE. Is this something you have seen before? Any tips on what could be the issue?

```
$ ./usb_sniffer_linux --mcu-sram usb_sniffer.bin
Uploading 3187 bytes into the FX2LP SRAM
...done
$ ./usb_sniffer_linux  --mcu-eeprom usb_sniffer.bin
Error: incorrect FPGA IDCODE (0x00000000)
$
```
On kernel.log, I see

```
Jan 31 13:04:14 mbradmin-System-Product-Name kernel: [938797.213555] usb 1-6: new high-speed USB device number 25 using xhci_hcd
Jan 31 13:04:15 mbradmin-System-Product-Name kernel: [938797.361730] usb 1-6: New USB device found, idVendor=04b4, idProduct=8613, bcdDevice=a0.01
Jan 31 13:04:15 mbradmin-System-Product-Name kernel: [938797.361733] usb 1-6: New USB device strings: Mfr=0, Product=0, SerialNumber=0
Jan 31 13:04:15 mbradmin-System-Product-Name kernel: [938797.362149] usbtest 1-6:1.0: FX2 device
Jan 31 13:04:15 mbradmin-System-Product-Name kernel: [938797.362152] usbtest 1-6:1.0: high-speed {control bulk-in bulk-out} tests (+alt)
Jan 31 13:04:57 mbradmin-System-Product-Name kernel: [938840.009639] usb 1-6: USB disconnect, device number 25
Jan 31 13:04:58 mbradmin-System-Product-Name kernel: [938840.529418] usb 1-6: new high-speed USB device number 26 using xhci_hcd
Jan 31 13:04:58 mbradmin-System-Product-Name kernel: [938840.680478] usb 1-6: New USB device found, idVendor=6666, idProduct=6620, bcdDevice= 1.00
Jan 31 13:04:58 mbradmin-System-Product-Name kernel: [938840.680481] usb 1-6: New USB device strings: Mfr=1, Product=2, SerialNumber=3
Jan 31 13:04:58 mbradmin-System-Product-Name kernel: [938840.680482] usb 1-6: Product: USB Sniffer
Jan 31 13:04:58 mbradmin-System-Product-Name kernel: [938840.680483] usb 1-6: Manufacturer: Alex Taradov
Jan 31 13:04:58 mbradmin-System-Product-Name kernel: [938840.680484] usb 1-6: SerialNumber: [-----SN-----]
```

ataradov, 2024-01-31:
Double check that your FPGA is soldered correctly and that it is a correct device. Post pictures of the assembled board. There is not much you can tell from the logs, since you will get the same exact result even if FPGA is not soldered at all.

anujdeshpande, 2024-02-01:
@ataradov here's a pic -

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

ataradov, 2024-02-01:
Your FPGA is soldered in the wrong orientation. Pin 1 is marked by the small dot.

anujdeshpande, 2024-02-01:
Yeah - just figured it out. I feel stupid now :/
Thanks for the help

Closed 2024-02-01.

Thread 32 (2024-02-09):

Improvement: please move GND and 3V3 vias from FPGA pins

acassis, 2024-02-09:
Hi Alex, first of all thank you for this great project.

I had a hard time doing hardware debug because of these vias near FPGA pins:

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

Because I'm soldering manually with hot iron, the solder move very easily to these vias. I removed many components until I found this issue. After cutting the wire from C8 to 3V3 in the other side of the board the issue disappeared.

Maybe you could move the vias from C5, C7 and C9 too, because they also could end up causing similar issue.

ataradov, 2024-02-09:
I won't be making hardware changes just for that. And I don't expect any other hardware changes. This is my standard clearance and I never had any issues soldering those devices by hand.

Provided Gerber files specify tented vias. You would have to try really hard to create shorts. I don't even know how I would do that if I wanted to.

You likely need to use a better soldering equipment or techniques.

acassis, 2024-02-09:
Hi @ataradov,
actually I just soldered using the standard way I used to solder many other projects (that is basically as [doogulass](https://www.youtube.com/@doogulass) did in this video as well.

So no, I didn't "tried hard to create the shorts".

I only opened it issue to help making it easier for other people doing it, I didn't expect you receiving it as a criticism. The only purpose was to avoid other people facing same issues I faced. I manufactured the board at JLCPCB that has a good quality, so it was not the soldermask getting removed easily.

I suspect the solder flowed from bottom side (lower pad of C8) and made contact with some FPGA pin or the GND via at side of it. BTW, this is just a supposition because I don't have x-ray machine here to confirm my suspect.

ataradov, 2024-02-09:
Your description does not match the possible short you are describing.  If the short is under the IC, how would removing C8 help it? It is much more likely that C8 itself has a short.

The solder flow you are describing is extremely hard to achieve.

acassis, 2024-02-10:
I didn't remove C8, I just did a sharp cut the wire trace from C8 via to 3V3 (that I cold re-wire again with a drop of solder) and the short disappeared.

ataradov, 2024-02-10:
Which is equivalent to removing the C8 from the circuit. If the short was on the other side of the board under the IC, then doing that cut would not have solved the issue.

If you still have C8 disconnected, then you can measure it for continuity. If there was a short, it would be in C8.

Closed 2024-03-18.

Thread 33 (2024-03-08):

Transfer rate:  0.00 MB/s

Spoosie, 2024-03-08:
Hi, and thanks for this cool project. I have build the hardware and programmed the MCU und FPGA. Everything worked fine until the test procedure.
I got 0.00 MB/s at the transfer speed, and i have no clue what i can do to fix that!
Could you give me a hint?

ataradov, 2024-03-08:
Most likely you have some issues with the USB PHY IC and it is not producing 60 MHz clock. Up to the test point it would matter, but the test part needs it.

So, measure that clock and the input 26 MHz clock.

acassis, 2024-03-19:
I faced similar issue: https://www.youtube.com/watch?v=3Boyl4IId2g

I checked the 26MHz clock and it is fine, so probably is some issue on USB3343, right?

ataradov, 2024-03-19:
Do you see 60 MHz as well? If not, then yes, something is wrong with the USB PHY. It should start producing 60 MHz clock for the FPGA. Without it programming will work, but no data will be sent.

ataradov, 2024-03-19:
And the most obvious thing to check that is it soldered in a correct orientation.

acassis, 2024-03-19:
I think the orientation is correct because I looked the datasheet before soldering, see attached image.

The 60MHz should be on pin 2 of USB3343, correct? So, that could be the issue, there is nothing on this pin!
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

ataradov, 2024-03-19:
Yes, this looks like a correct orientation. And yes, pin 2 should have 60 MHz.

Another thing to double check is that you have  8.06K (R11) resistor mounted and the value is correct. Apparently, it does not produce any clock when this resistor is not mounted.

acassis, 2024-03-19:
Yes, it is mounted, but I checked on multimeter and its value is 8.25K. Is it inside the tolerance range?

ataradov, 2024-03-19:
It needs to be 8.06 +/- 1%. So, it should be in the range 7.98 - 8.14 kOhm. I don't know what will happen if it is outside of that range. I don't think it is that sensitive for the purpose of the clock generation, but who knows.

jpenalbae, 2024-05-14:
I have had this same issue and wanted to share here in case others happen to find this thread when searching on how to solve the problem.

In mi case it was bad soldering on the USB3343. I guess it can be a bit tricky to solder by hand...

I fixed it just by de-soldering and re-soldering the USB3343. First remove all the solder in the IC and the board. Prime the ground pad with very little solder, using the heat gun solder the IC as usual, press down with a pair of tweezers on the IC until everything cools down to make sure it properly seats and its not floating on the solder pad. Next using a good amount of flux solder the external pins, I would recommend drag soldering technique there.

acassis, 2024-05-14:
@jpenalbae Thank you Jaime, that was my suspicious too! I didn't have the change to resolder it yet. How are you testing it? Did you connect some device to J2 (USB-C) connector during the speed test?

ataradov, 2024-05-14:
Speed test only needs host connection, target can be disconnected. The only reason USB3343 is necessary for the test to work is that it provides 60 MHz clock that is needed for everything to work.

jpenalbae, 2024-05-14:
> @jpenalbae Thank you Jaime, that was my suspicious too! I didn't have the change to resolder it yet. How are you testing it? Did you connect some device to J2 (USB-C) connector during the speed test?

I would try to re-soldering the same USB3343 you have in the board right now, that is what I did. If that didn't work I was planing on trying with a new one, but it wasn't necessary in my case.

For testing, as have been already mentioned around here, make sure 26MHz clock in, 60MHz clock out, download the datasheet for USB3343 and double check everything is in place. For my case it was pretty obvious cause besides the 60MHz clock, the integrated 1.8v LDO (pin 23) wasn't working either, so it was a bad USB3343 or a bad solder job.

kevinaangstadt, 2024-06-07:
I have the same issue, as well; however, I am able to measure 60MHz at the FPGA.  Any pointers on where to look next?

ataradov, 2024-06-07:
Was FPGA firmware upload correctly? Is the FPGA type (including speed grade) correct?

kevinaangstadt, 2024-06-07:
> Was FPGA firmware upload correctly? Is the FPGA type (including speed grade) correct?

Flashing the FPGA appears to succeed:

```shell
$ ./usb_sniffer_linux --fpga-flash usb_sniffer_impl.jed
Programming FPGA flash
Erasing flash
Programming configuration data .....
Verifying configuration data
Programming and verifying Feature Row
Programming and verifying FEABITS
Exiting programming mode
...done
```

I purchased a LCMXO2-2000HC-5TG100C from DigiKey, which I believe matches what is specified in the BOM.

ataradov, 2024-06-07:
Yes, this all this is correct. The other thing to check is that you have 30 MHz on the IFCLK (FPGA pin 88). This clock is generated by the MCU and FPGA is using it to send the data.

And check CTRL_CLK/CTRL_DATA. Those pins are used to enable the test mode. There is no persistent clock on them, but they should some activity when the test mode is started.

All those signals go from the MCU to the FPGA, so check on the FPGA side, so you verify soldering on both sides at the same time.

kevinaangstadt, 2024-06-07:
Thanks! I found a few loose pins on the MCU. After fixing those, I'm seeing 40-50MB/s as expected.

Spoosie, 2024-06-24:
> Hi, and thanks for this cool project. I have build the hardware and programmed the MCU und FPGA. Everything worked fine until the test procedure. I got 0.00 MB/s at the transfer speed, and i have no clue what i can do to fix that! Could you give me a hint?

Okay, after a long time i came back to this project. And i found a heavy bug. I had to rotate the USB3343 about 90 degrees. Uhaa.. hopefully the chip was not damaged!

But after a short test i got the desired 40-50MB/s. That's fine!

Now i got some other errors with the wireshark capture. I would like to test some sticks laying around, but all of them are not really send the right datas. I got "USB PHY Error". Could it be, that the USB3343 is faulty because of my lack of competence? :-/ Maybe i should order a new one, and try it out.

ataradov, 2024-06-24:
Did you configure the correct capture speed? If yes, then I would assume the PHY is damaged and replace it before spending more time investigating that.

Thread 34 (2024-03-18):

USB failing during the enumeration

acassis, 2024-03-18:
Hi Alex, because that short-circuit issue under the FPGA I decided to take a different approach: starts from basic and get USB Host working first!

I soldered only the USB Host on another board (all the components of Kicad schematic page 3, the J1 connector and its resistors and IC2 regulators and its components), after that I tried to connect it to computer it was detected and almost immediately it was disconnected:

```
[35566.856268] usb 3-5: new high-speed USB device number 5 using xhci_hcd
[35567.072707] usb 3-5: New USB device found, idVendor=04b4, idProduct=8613, bcdDevice=a0.01
[35567.072721] usb 3-5: New USB device strings: Mfr=0, Product=0, SerialNumber=0
[35567.224368] usbtest 3-5:1.0: FX2 device
[35567.224373] usbtest 3-5:1.0: high-speed {control bulk-in bulk-out} tests (+alt)
[35567.224434] usbcore: registered new interface driver usbtest
[35571.954145] usb 3-5: USB disconnect, device number 5
[35572.328136] usb 3-5: new high-speed USB device number 6 using xhci_hcd
[35572.544706] usb 3-5: New USB device found, idVendor=04b4, idProduct=8613, bcdDevice=a0.01
[35572.544718] usb 3-5: New USB device strings: Mfr=0, Product=0, SerialNumber=0
[35572.545598] usbtest 3-5:1.0: FX2 device
[35572.545605] usbtest 3-5:1.0: high-speed {control bulk-in bulk-out} tests (+alt)
[35575.855084] usb 3-5: USB disconnect, device number 6

$ sudo lsusb
Bus 004 Device 001: ID 1d6b:0003 Linux Foundation 3.0 root hub
Bus 003 Device 004: ID 8087:0026 Intel Corp. AX201 Bluetooth
Bus 003 Device 003: ID 0c45:672e Microdia Integrated_Webcam_HD
Bus 003 Device 002: ID 27c6:63ac Shenzhen Goodix Technology Co.,Ltd. Goodix USB2.0 MISC
Bus 003 Device 001: ID 1d6b:0002 Linux Foundation 2.0 root hub
Bus 002 Device 001: ID 1d6b:0003 Linux Foundation 3.0 root hub
Bus 001 Device 001: ID 1d6b:0002 Linux Foundation 2.0 root hub
$
```

Initially I was thinking my 24MHz oscillator was faulty, because I'm using the ECS-3225MVLC-240-CN-TR that @casandra9 suggested, but I looked at CKOUT pin in the oscilloscope and it is generating 12MHz as expected.

Did you face similar issue in the past? How to debug/fix this issue?

ataradov, 2024-03-18:
This looks like a poor physical connection in the connector or a broken USB cable or something like that. If it gets to that point, it means it is mostly working and clocks are fine.

I would do this - connect the cable on the PCB side and make sure that PCB plus that end of the cable is not moving. Then plug in the other end of the cable into the PC. See if the behavior repeats. With a poor connection and a stationary PCB I would expect it to either work or not, but not this intermittent behavior.

casandra9, 2024-03-19:
[Quote](…) New USB device strings: Mfr=0, Product=0, SerialNumber=0 (…)[\Quote]

Could it be that you didn’t program the FW?

ataradov, 2024-03-19:
This is just a raw blank FX2LP device. This enumeration happens on the hardware level, there is no firmware at this point. But it still should not disconnect. There is no real point in programming the real FW if this mode does not work reliably. The real FW won't either.

acassis, 2024-03-19:
Thank you @ataradov I'll verify the USB-C soldering, because I didn't use much solder on its pads to avoid short-circuiting the pads, maybe it is not well soldered.

@casandra9 as @ataradov explained it is a blank device, so it is a chicken-egg dilemma, because the device is disconnecting just after plugging the case I cannot flash the firmware yet.

acassis, 2024-03-19:
In fact it was the USB-C connector that wasn't well soldered:

```
[ 1844.234868] usb 3-3: new high-speed USB device number 5 using xhci_hcd
[ 1844.383410] usb 3-3: New USB device found, idVendor=04b4, idProduct=8613, bcdDevice=a0.01
[ 1844.383414] usb 3-3: New USB device strings: Mfr=0, Product=0, SerialNumber=0
[ 1844.511175] usbtest 3-3:1.0: FX2 device
[ 1844.511178] usbtest 3-3:1.0: high-speed {control bulk-in bulk-out} tests (+alt)
[ 1844.511228] usbcore: registered new interface driver usbtest
[ 1850.322958] ucsi_acpi USBC000:00: GET_CONNECTOR_STATUS failed (-110)
[ 1856.466951] ucsi_acpi USBC000:00: GET_CONNECTOR_STATUS failed (-110)
alan@dev:~$ sudo lsusb
Bus 004 Device 001: ID 1d6b:0003 Linux Foundation 3.0 root hub
Bus 003 Device 005: ID 04b4:8613 Cypress Semiconductor Corp. CY7C68013 EZ-USB FX2 USB 2.0 Development Kit
Bus 003 Device 004: ID 8087:0026 Intel Corp. AX201 Bluetooth
Bus 003 Device 003: ID 0c45:672e Microdia Integrated_Webcam_HD
Bus 003 Device 002: ID 27c6:63ac Shenzhen Goodix Technology Co.,Ltd. Goodix USB2.0 MISC
Bus 003 Device 001: ID 1d6b:0002 Linux Foundation 2.0 root hub
Bus 002 Device 001: ID 1d6b:0003 Linux Foundation 3.0 root hub
Bus 001 Device 001: ID 1d6b:0002 Linux Foundation 2.0 root hub
$
```

Thank you Alex! Let's move on!

Closed 2024-03-19.

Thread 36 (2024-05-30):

Digikey BOM & Comparison to Lite

dderiso, 2024-05-30:
Dear Alex,

Thank you for sharing such a great project!

If it helps others, here is a DigiKey cart: https://www.digikey.com/short/jqrb2558

Do these parts look about right? Do you happen to know your USB MPNs?

Cheers,
Dave

PS.

This RPi version also looks great

https://github.com/ataradov/usb-sniffer-lite

Which do you recommend for new users?

ataradov, 2024-05-30:
The list seems fine, but the prices compared to LCSC are steep.

USB connectors used here are very generic, there are dozens of options that would work. On a quick look, this should work:
https://www.digikey.com/en/products/detail/amphenol-cs-commercial-products/12402012E212A/13683192
https://www.digikey.com/en/products/detail/te-connectivity-amp-connectors/6364372-2/2286712

The USB-A side is designed for a connector with flat mounting pins, but if you are doing manual assembly, then more common connectors like this https://www.digikey.com/en/products/detail/on-shore-technology-inc/USB-A1HSB6/2677751 would also work, you may just need to straighten out the mounting pins.

If you have a way to build the full one, I would always recommend doing that. The Lite one is good because most people will have a Pi Pico and an old USB cable, so anyone can build it in 15 minutes.

dderiso, 2024-05-31:
Awesome! Thank you!

On Thu, May 30, 2024 at 7:00 AM Alex Taradov ***@***.***>
wrote:

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

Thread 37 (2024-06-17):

The CH340 USB-to-serial converter is encountering substantial delays in data visualization.

blueoce, 2024-06-17:
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

The screenshot above shows data being sent by a serial port assistant. Although there is data, it is displayed very slowly and requires a long wait. Sometimes, it is even impossible to wait for the data to be displayed.

My question is that the delay in displaying the data is too large. Can the USB protocol filtering be placed on an FPGA for processing? This way, the display speed will be much faster and there will be no lagging.

ataradov, 2024-06-17:
Please don't send the same request in multiple places at the same time.

I'm not sure I understand the issue. CH340 is a full speed device. There should not be any lag in capturing the data.  If you see lag, there may be something wrong with your setup. May be the PC is too slow to run Wireshark or something like that.

In general, anything is possible if you spend enough time working on it. It is not possible with the current sniffer architecture, since it just passes the data to the host.

blueoce, 2024-06-17:
Test Method:

Reopen the capture for CH340.

Utilize a serial port assistant to send 5 packets of data.

Halt the capture on CH340.

Employ the search function to look for data "DATA," but no instances of any of the sent packets are detected.

Issue: The data has indeed been transmitted, yet no data is visible within Wireshark's capture interface. Strangely, if I wait for an extended period, these 5 packets eventually appear. I'm unsure where the data is getting stuck and need guidance on how to proceed with further troubleshooting.

测试方法：
1 重新打开捕捉CH340.
2 用串口助手，发送5包数据。
3 暂停捕捉CH340.
4 用搜索功能，查找数据DATA，没有发现任何一包数据。
问题：数据已经上传了，但是在Wireshark的捕捉数据界面没有发现任何数据。
但是如果等很久，这个5包数据还是会上传的，我不知道数据到底卡在哪里了，如何进行下一步的排查呢？

285524959
***@***.***

&nbsp;

------------------&nbsp;原始邮件&nbsp;------------------
发件人:                                                                                                                        "ataradov/usb-sniffer"                                                                                    ***@***.***&gt;;
发送时间:&nbsp;2024年6月18日(星期二) 凌晨0:00
***@***.***&gt;;
***@***.******@***.***&gt;;
主题:&nbsp;Re: [ataradov/usb-sniffer] The CH340 USB-to-serial converter is encountering substantial delays in data visualization. (Issue #37)

Please don't send the same request in multiple places at the same time.

I'm not sure I understand the issue. CH340 is a full speed device. There should not be any lag in capturing the data.  If you see lag, there may be something wrong with your setup. May be the PC is too slow to run Wireshark or something like that.

In general, anything is possible if you spend enough time working on it. It is not possible with the current sniffer architecture, since it just passes the data to the host.

—
Reply to this email directly, view it on GitHub, or unsubscribe.
You are receiving this because you authored the thread.Message ID: ***@***.***&gt;

ataradov, 2024-06-17:
There are multiple buffers present in the system, but they all are designed to be flushed reasonably fast. There should be no significant delays, nothing more than a couple seconds.

I don't really know what is going on. It is hard to tell without more information.

Do a simple test - start the capture, connect the device, open a COM port in a terminal program, send one byte. Do you observe this byte immediately or with the delay? Do you observe the delay in the other frames (getting the descriptors)?

blueoce, 2024-06-17:
Test Method:

Reopen the capture for CH340.

Utilize a serial port assistant to send 5 packets of data.

Halt the capture on CH340.

Employ the search function to look for data "DATA," but no instances of any of the sent packets are detected.

When the CH340 is initially plugged in, the data capture is very quick, with no discernible delay. 开始插入CH340时候，数据捕捉是非常快的。感觉不到延迟。

&nbsp;However, as the number of data packets increases, a substantial delay occurs, and in some cases, data is not received at all.但是当分组数据多了以后，就会出现大量的延时，甚至收不到数据。

Issue: The data has indeed been transmitted, yet no data is visible within Wireshark's capture interface. Strangely, if I wait for an extended period, these 5 packets eventually appear. I'm unsure where the data is getting stuck and need guidance on how to proceed with further troubleshooting.

285524959
***@***.***

&nbsp;

------------------&nbsp;原始邮件&nbsp;------------------
发件人:                                                                                                                        "ataradov/usb-sniffer"                                                                                    ***@***.***&gt;;
发送时间:&nbsp;2024年6月18日(星期二) 凌晨1:12
***@***.***&gt;;
***@***.******@***.***&gt;;
主题:&nbsp;Re: [ataradov/usb-sniffer] The CH340 USB-to-serial converter is encountering substantial delays in data visualization. (Issue #37)

There are multiple buffers present in the system, but they all are designed to be flushed reasonably fast. There should be no significant delays, nothing more than a couple seconds.

I don't really know what is going on. It is hard to tell without more information.

Do a simple test - start the capture, connect the device, open a COM port in a terminal program, send one byte. Do you observe this byte immediately or with the delay? Do you observe the delay in the other frames (getting the descriptors)?

—
Reply to this email directly, view it on GitHub, or unsubscribe.
You are receiving this because you authored the thread.Message ID: ***@***.***&gt;

blueoce, 2024-06-17:
285524959
***@***.***

&nbsp;

------------------&nbsp;原始邮件&nbsp;------------------
发件人:                                                                                                                        "285524959"                                                                                    ***@***.***&gt;;
发送时间:&nbsp;2024年6月18日(星期二) 凌晨1:22
***@***.******@***.***&gt;;
***@***.***&gt;;
主题:&nbsp;回复： [ataradov/usb-sniffer] The CH340 USB-to-serial converter is encountering substantial delays in data visualization. (Issue #37)

Test Method:

Reopen the capture for CH340.

Utilize a serial port assistant to send 5 packets of data.

Halt the capture on CH340.

Employ the search function to look for data "DATA," but no instances of any of the sent packets are detected.

When the CH340 is initially plugged in, the data capture is very quick, with no discernible delay. 开始插入CH340时候，数据捕捉是非常快的。感觉不到延迟。

&nbsp;However, as the number of data packets increases, a substantial delay occurs, and in some cases, data is not received at all.但是当分组数据多了以后，就会出现大量的延时，甚至收不到数据。

Currently, the capture response for mouse devices and USB drives is swift, but there seems to be a noticeable lag or sluggishness when capturing data from the CH340 USB-to-serial conversion. 目前捕捉 鼠标设备和U盘设备，捕捉响应速度都很快，就是感觉CH340_USB转串口响应卡顿。

Issue: The data has indeed been transmitted, yet no data is visible within Wireshark's capture interface. Strangely, if I wait for an extended period, these 5 packets eventually appear. I'm unsure where the data is getting stuck and need guidance on how to proceed with further troubleshooting.

285524959
***@***.***

&nbsp;

------------------ 原始邮件 ------------------
发件人:                                                                                                                        "ataradov/usb-sniffer"                                                                                    ***@***.***&gt;;
发送时间:&nbsp;2024年6月18日(星期二) 凌晨1:12
***@***.***&gt;;
***@***.******@***.***&gt;;
主题:&nbsp;Re: [ataradov/usb-sniffer] The CH340 USB-to-serial converter is encountering substantial delays in data visualization. (Issue #37)

There are multiple buffers present in the system, but they all are designed to be flushed reasonably fast. There should be no significant delays, nothing more than a couple seconds.

I don't really know what is going on. It is hard to tell without more information.

Do a simple test - start the capture, connect the device, open a COM port in a terminal program, send one byte. Do you observe this byte immediately or with the delay? Do you observe the delay in the other frames (getting the descriptors)?

—
Reply to this email directly, view it on GitHub, or unsubscribe.
You are receiving this because you authored the thread.Message ID: ***@***.***&gt;

ataradov, 2024-06-17:
Please respond on GitHub directly. Those email responses are impossible to read.

How long do you need to wait until the delays occur? Even when no actual data is sent, USB generates a lot of packets like SOFs and other polling. Eventually you will run out of RAM on your PC.

blueoce, 2024-06-17:
After approximately 30 seconds, the CH340 starts to experience noticeable lag, to the point where it feels like data might be getting lost.  30秒之后，就会CH340就会出现卡顿，甚至感觉卡到丢失数据。
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

When testing with a mouse device, similar lag issues do not arise; neither do they occur with USB drive devices.

测试鼠标设备，不会出现类似卡顿的问题，U盘设备也不会卡顿。

blueoce, 2024-06-17:
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
The screenshot above shows the test results for a USB mouse device. Regardless of how long the test runs, data upload remains swift and experiences no lag.
上图是测试USB鼠标设备的截图，不论测试多久，数据上传都很快。不会卡顿。

ataradov, 2024-06-17:
This is strange. There is no real difference between the mouse and the CH340.

One thing I can suggest is enable folding of the empty frames in the sniffer settings. All those IN/NAK pairs will be condensed a lot.

blueoce, 2024-06-17:
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
USB flash drive devices also respond very quickly.   U盘设备响应也非常快。

ataradov, 2024-06-17:
Resolved how? By enabling folding?  It is strange because the other devices would have generated similar number of frames.

blueoce, 2024-06-17:
For the CH340 device, it is necessary to enable the feature of folding empty data packets in the packet capture software; otherwise, it encounters lag or even becomes unresponsive. In contrast, the mouse device operates normally without requiring this adjustment, experiencing no lag or freezing issues.

ataradov, 2024-06-17:
I guess the polling is much slower on the mouse.

But yes, for long running captures, enabling the folding helps a lot. Note that this folding happens in the software on the PC side, but before it gets to the Wireshark. The hardware still sends all the frames.

So, the overall slowness is due to Wireshark itself. It gets slow trying to parse all those empty IN/NAK pairs.

blueoce, 2024-06-17:
By filtering out empty packets in Wireshark, a substantial amount of PC RAM is saved, which in turn enhances the computer's responsiveness.

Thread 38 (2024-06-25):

Hardware buffer overflow

blueoce, 2024-06-25:
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
The 2.0 USB drive passed the test without any issues, but the 3.0 USB drive encountered errors during testing。Hardware buffer overflow

ataradov, 2024-06-25:
This sniffer can only capture USB2 traffic, so USB3 devices would operate in a USB2 mode. There are a couple possible reasons for the differences - your USB3 device is much faster in USB2 mode than the real USB2 device, or the system enumerates it differently and allocates more bandwidth to it.

What does the speed test say about your connection speed? In both cases with the drive connected and not.

Try different combinations for USB ports for the the sniffer and the target device.

blueoce, 2024-06-25:
Here are the test results without the USB drive plugged in.
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

blueoce, 2024-06-25:
Below are the test results with the USB drive plugged in.
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

ataradov, 2024-06-25:
This is quite good. Assuming that it does not change with USB drive plugged in, there is no real way to avoid those overflows. Long capture is bound to overflow at some point, since USB sniffer captures the same data, but also needs to carry additional information on the timestamps and line states. So, capturing any device that is efficient at utilizing the bandwidth will have overflows.

blueoce, 2024-06-25:
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
What methods can I employ to enhance the transfer speed, as illustrated in the aforementioned diagram? What considerations should I take into account to achieve an improvement?

ataradov, 2024-06-25:
As I said, run the capture from the command line. The same way you run the speed test. This sniffer does not need Wireshark to run, it can capture into the pcapng file from the command line. Then open that file in Wireshark.

Run "usb_sniffer -h", it will show you the help message. You will need to run something like this: "usb_sniffer -s hs -c -f capture.pcapng"

blueoce, 2024-06-25:
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
It seems that it's still not working. Could it be due to the excessive amount of data?

ataradov, 2024-06-25:
The overflows will happen, this is inevitable. Your goal with the command line test is to see if you get fewer of them compared to the Wireshark. So, just looking at the filtered result is not helpful.

The maximum 4 ms processing time is pretty good. If you don't see values much higher than that, then your processing is fast enough.

It is physically impossible to capture all data and send it along with the meta information over the channel with the same bandwidth as the captured channel.

This sniffer is not meant to capture all the data. This is a debugging tool. When debugging basic transfers, you should setup a test where short files are transferred. And when debugging some long running issue, you can assume that data in the packets is correct, and missing the exact value is fine.

The other alternative is to slow down the transfer. Use a separate PC for the target device connection with a slower USB performance. It is hard to tell what may work exactly here. But using some very low power device, like Raspberry Pi or similar may help. This way target USB will not be as fast and it will not fully utilize USB bandwidth.

Also, was your speed test with USB drive plugged in while the large file was transferred? Or just the drive plugged in doing nothing? You need to recreate the same conditions as would be present during capture.

blueoce, 2024-06-25:
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
Just plug in the USB drive without performing any operations.

blueoce, 2024-06-25:
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
Perform the operation of reading the USB drive, specifically checking the properties of the files within it.

ataradov, 2024-06-25:
Do the speed test while a big file transferred to/from USB drive.

Just plugging in the drive should not cause this many overflows, unless OS does some big reads right after.

blueoce, 2024-06-25:
After formatting the USB drive, inserting it no longer results in errors.

blueoce, 2024-06-25:
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
Even when writing content less than 1MB, a substantial amount of overflow occurs.

ataradov, 2024-06-25:
On a low level of USB transfers, formatting does not mater. It is likely that formatting just removed the files and OS no longer needs to read them. It is hard to tell what it was doing exactly. It may have been thumbnail generation for videos and images, or virus scan, or search indexing.

The guaranteed buffers are just a few KB. Anything else may overflow. This is normal and expected. If you want full capture, you will have to use a much more complicated equipment with USB 3.0 port of the capture side and much bigger buffers.

Do  the speed test while transferring large file over USB. You may have a port that is shared by the same host controller, which will reduce the bandwidth available to the sniffer. And OS may prioritize scheduling of transfer for the flash drive.

If the speed drops during that tests, then you will need to experiment with using different USB ports. And the best case is to use a separate PCs for the capture and for the target.

blueoce, 2024-06-25:
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
Two computers have already been tested, with one dedicated to the sniffer for data capture and the other for reading and writing to the USB drive. However, even when simply plugging in the USB drive, there are still a substantial number of error messages being reported.

blueoce, 2024-06-25:
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
Two computers have already been tested, with one dedicated to the sniffer for data capture and the other for reading and writing to the USB drive. However, even when simply plugging in the USB drive, there are still a substantial number of error messages being reported.

ataradov, 2024-06-25:
There is not much you can do if the target device is faster (or the same speed) than the capture port. The only thing that may help is using way slower computer for the target (like RPi) and hope that it can't schedule USB transfers as fast.

Or just deal with the missing frames. When debugging, you can infer that there was a large frame, which is likely a data frame. And when debugging issues with individual data frames, you are not likely to look though GBs of data, you really need to setup an experiment where you can capture the fault quickly. Ans when debugging a custom device, there is a trigger input to enable capture only at critical moments.

This tool was never intended to be able to capture all the data. It is simply impossible without massive local buffers or using USB3 for the sniffer port.

blueoce, 2024-06-25:
I've just conducted a test, and it appears that using a USB hub doesn't help either; the speed remains high, which still leads to frequent errors.

ataradov, 2024-06-25:
Hubs are pretty efficient, they won't slow things down a lot. You will need a host that is not as good as scheduling transfers. And that is not easy to setup.

desowin, 2024-08-02:
To slow down the transfer use high-speed hub and plug multiple devices to hub downstream ports:
- the device-under-test (monitor the link between hub and device-under-test)
- high-speed device(s) that use IN isochronous or interrupt transfer. If you get device that does high-bandwidth 3 * 1024 periodic transfers on every microframe that device alone will consume around 48.5% of total bandwidth, essentially depriving the device-under-test from that bandwidth.

Note that OUT transfers won't help you because these will be visible on the device-under-test link. The IN transfers (and ACKs in case of interrupt transfers) for the other device will still be visible but the data response won't be visible. The goal is to have as many IN DATA packets with 1024 bytes payload as possible.

A less effective alternative is to get large USB 3 capable SSD (significantly larger than available RAM on host), connect it to the high-speed hub and issue `while true; do dd if=/dev/sdX of=/dev/null; done`. There will be significantly more unwanted data from host, but it might do the trick. That way you get quite some IN DATA packets with 512 bytes payload.

If you just want to force full-speed operation of device-under-test (note: the device might not implement all the functionality at high-speed) just connect it to host via ADUM3160 isolator or similar.

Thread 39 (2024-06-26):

capture trigger: 'disabled' (default), 'low', 'high', 'falling' or 'rising'

blueoce, 2024-06-26:
It feels akin to utilizing an external triggering function, similar to the level triggering feature in a logic analyzer.How do I use it?

ataradov, 2024-06-26:
The trigger is really only useful when you are debugging your own devices. In that case you can set up a GPIO pin to toggle at the interesting parts of the firmware flow. This way you can either capture just an interesting sequence of frames out of a long run time.

Or in the simplest case you can just log level transition on the trigger input. This way you can mark events in the firmware and have them related to the frames on the line. Those events will be timestamped the same way as the regular packets. So, you can set a GPIO when you submit a request to send the data and then time how long it took from the request to the packet appearing on the line.

blueoce, 2024-06-26:
Which GPIOs can be configured for external triggering with a sniffer, and after setting up external triggering, how do I choose which GPIO to use for capturing external events? Could you provide an example or suggest where I might find relevant materials?

ataradov, 2024-06-26:
GPIOs on the device you are debugging when you develop your own firmware. It depends entirely on your target hardware.

From the sniffer point of view you have two pins - ground and the trigger input. By default there is a pull-up on the trigger input. You can start the capture and short the tow pins - you will see messages in the log corresponding to the edge transitions.

If you set it to 'low', then the capture would only happen while you are shorting the pins. If you set it to 'high', then the capture would be paused while you are shorting the pins. If you set it to 'falling', then the capture would start as soon as you short the pins and will continue indefinitely.

Manual shorting is not that useful, obviously. But you can connect the ground to the target ground (there is already a connection over the target USB ground, but more direct connection would not hurt). And the trigger input could be connected to some GPIO pin on the target device. Now when you toggle that GPIO on the target device, you will see timestamped entries in the log.

All of this applies if you are developing your own firmware and not just looking at existing devices.

blueoce, 2024-06-26:
To enable external triggering functionality, do I need to write my own firmware, as it's not supported by the existing sniffer firmware? Would modifying just the FPGA code suffice?

ataradov, 2024-06-26:
No, I'm talking about your firmware on your USB MCU. It has nothing to do with the sniffer. The sniffer functionality is all there. I described how you can test it without any external hardware by simply shorting the trigger pins.

This sniffer is primarily a development tool. It is meant for people making their own USB devices.

blueoce, 2024-06-27:
the IO_IN pin on the FPGA is typically internally pulled up, meaning i woin't see an external pull-up resistor on the circuit board.

ataradov, 2024-06-27:
Yes, IO_IN uses FPGA pull-up resistor. When nothing is connected, it has a high level. This is why when you short it to ground, the level becomes low and you see a corresponding message in the capture log.

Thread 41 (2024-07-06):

Smaller packages - QFN or BGA

phodina, 2024-07-06:
Hi @ataradov,

could you please suggest components that take less space and provide the same functionality? I mean are there compatible parts Cypress CY7C68013A MCU, Lattice LCMXO2 FPGA in QFN or BGA packages?

I understand that these part will impact the necessary skills to solder the components at home.

However, it would be nice if it could be fitted into smaller form factor like Framework module.
https://github.com/FrameworkComputer/ExpansionCards/tree/main/Mechanical

ataradov, 2024-07-06:
CY7C68013A is available in QFN-56 and it should work exactly the same.
XO2-2000 is available in 132 pin BGA package. I don't know if the same pins are available on this package, FPGA project changes would likely be required.

At the same time, physical dimension are defined by the target connectors. Their layout is fixed and limited by the cable connectors. You can't place them much closer or make USB-A connector smaller.

Plus I don't see what is the benefit of making that a module. The sniffer is meant to be an external tool.

phodina, 2024-07-07:
Thanks for the components. Yes, probably there would be need to generate new bitstream for the FPGA.

Sure, the connectors can be downscaled and in theory it does not matter as you say it should be used externally.

Basilisvirus, 2024-12-26:
Note that the existing CY7C68013A-56PVXC IC has been marked as end of life.
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

ataradov, 2024-12-26:
I would expect them to be available for a long time and there are at least 3 different clones. All the new stuff from Cypress is in unusable packages, so I'll pass on moving on to that.

Closed 2024-07-07.

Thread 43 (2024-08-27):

USB HS not passing all the data from host to device

sx107, 2024-08-27:
I am making a USB HS sound card on STM32H750. When I plug it in directly into usb port, everything works, but when I plug it in through the sniffer into the same port, packets are missing. Also, seems like I don't see any isochronous packets in wireshark. What am I doing wrong? The problem occurs even when the sniffer and sound card are plugged into different computers.

ataradov, 2024-08-27:
USB sniffer is not entirely transparent, as any intermediate device, it will introduce some signal loss. So, some performance degradation is to be expected. You can improve the situation by using shorter and better quality cables. I would use USB 3.0 cables because they generally have better quality. Many USB2 cables are not even close to meeting the specification requirements. I would especially avoid flexible silicone insulated cables. They are very convenient, but are really bad for signal integrity.

I personally seen improvement with this cable  https://www.amazon.com/gp/product/B01GGKYR2O

Also check that the PCB is clean from flux residue, especially on the front-end side. Many no-clean fluxes end up being conductive when not fully activated.

It may also indicate that the design is already marginal and the sniffer brings it over the edge. Check the sniffer with a few commercially available USB HS devices. Does it work in that case?

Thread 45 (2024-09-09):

EEPROM programing failes with 'Error: usb_i2c_read(): LIBUSB_ERROR_TIMEOUT'

Morpheus-79, 2024-09-09:
I can't finish the build since i'm stuck at programing the EEPROM. Loading the firmware into the SRAM works fine and:

_usb_sniffer_win.exe --mcu-sram usb_sniffer.bin_

... outputs:

_Uploading 3187 bytes into the FX2LP SRAM_
_...done_

But when trying:

_usb_sniffer_win.exe --mcu-eeprom usb_sniffer.bin_

... i always get:

_Programming 3187 bytes into the FX2LP EEPROM (SN: 44382301285c08)_
_Error: usb_i2c_read(): LIBUSB_ERROR_TIMEOUT_

I've tried different USB ports (connected to different USB host controllers) and tried programing the EEPROM under Linux too -> but every attempt ends with:

_Error: usb_i2c_read(): LIBUSB_ERROR_TIMEOUT_

I opted for some alternate parts, since the ones from the BOM weren't available at the time. For example i got a HG24LC128M/TR EEPROM:

https://www.lcsc.com/product-detail/EEPROM_HGSEMI-HG24LC128M-TR_C3007884.html

... and some different oscillators:

https://www.lcsc.com/product-detail/Crystal-Oscillators_Abracon-LLC-ASEDV-26-000MHZ-LR-T_C1857762.html
https://www.lcsc.com/product-detail/Crystal-Oscillators_Abracon-LLC-ASEDV-24-000MHZ-LR-T_C17564399.html

But this shouldn't be a problem... at least: i thought. Or did i miss something and one of these components is the culprit?

ataradov, 2024-09-09:
The problem would be somewhere around EEPROM. The oscillators are ok if it gets that far.

But this error is strange. This can only happen during data verification, which means that EEPROM worked well enough to at least pretend to write the data.

Build the PC application from code and put debug prints in the loop in the fx2lp_eeprom_upload() to see what iteration fails. This is the only place that does the reads.

ataradov, 2024-09-09:
Also, EEPROM may be extremely slow. So, I would also try to place os_sleep(10); between fx2lp_eeprom_write() and fx2lp_eeprom_read() in the same function.

Morpheus-79, 2024-09-09:
I've added some debug prints and got a read error at the start address after a successful write:

_Programming 3187 bytes into the FX2LP EEPROM (SN: 44382301285c08)_
_Writing to EEPROM at address 0x0_
_Write complete._
_Reading from EEPROM at address 0x0_
_Error: usb_i2c_read(): LIBUSB_ERROR_TIMEOUT_

Trying to write to the EEPROM a second time results in a write error at the start address:

_Programming 3187 bytes into the FX2LP EEPROM (SN: 44382301285c08)_
_Writing to EEPROM at address 0x0_
_Error: usb_i2c_write(): LIBUSB_ERROR_PIPE_

Since i've had a MiniPro TL866 laying around somewhere in the chaos of my home, i desoldered the EEPROM and tried to read it. After selecting an 24LC128 as chip device i was able to read the EEPROM... but it contained only a couple of the first bytes of the BIN file.

I resoldered the EEPROM. And since every writing attempt results in a corrupt firmware: i had to connect the board with the BOOT and VCC test points shorted to be able to give it another try. Loading the firmware into the SRAM worked as always. This time i tried to write to the EEPROM with a added _os_sleep(10)_ between writing and reading... but without any success:

_Programming 3187 bytes into the FX2LP EEPROM (SN: 44382301285c08)_
_Writing to EEPROM at address 0x0_
_Write complete. Sleeping..._
_Reading from EEPROM at address 0x0_
_Error: usb_i2c_read(): LIBUSB_ERROR_TIMEOUT_

I've now ordered some genuine Microchip 24LC32A EEPROMs from a local seller. Hopefully it'll fix this strange behaviour.

ataradov, 2024-09-09:
Yeah, I would not spend too much time debugging that. I would assume that something is fishy with those EEPROMs.

ataradov, 2024-09-09:
Also, you should be able to use the sniffer, you just need to upload the firmware every time you power cycle it. It will not have the correct serial number, but this should not cause any issues.

Morpheus-79, 2024-09-11:
You were absolutely right:

The 24LC32A EEPROMs arrived today... i replaced the fishy one... and:

_Programming 3187 bytes into the FX2LP EEPROM (SN: 44382301285c08)_
_...done_

... the problem was fixed.

Thanks for taking the time to help... and for this awesome project!

Closed 2024-09-11.

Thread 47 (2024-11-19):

InValid Packet ID ,When plugging in the USB cable to be tested,

blueoce, 2024-11-19:
1 the following figure,The correct way to plug in the USB cable to be tested is as follows:
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

2 the following figure,The correct display when plugging in the USB cable to be tested is as follows:
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

issue?
Does the 3343 chip have an issue? However, it works fine in other situations; the problem only occurs when plugging or unplugging the USB cable.

ataradov, 2024-11-19:
It is normal to see some connection noise (bouncing) when making a mechanical connection. The sniffer interprets that noise as data.

This is why all USB host stacks let the signals settle for 100-200 ms and then issue a bus reset when a new device is connected.

blueoce, 2024-11-19:
Can the error frames in Figure 2 be hidden, like in Figure 1，"If I encounter this issue, the only solution is to replace the USB 3343 chip！

blueoce, 2024-11-19:
Although replacing the USB3343 chip solved the problem, it suggests that the USB3343 was faulty. However, other functions were working normally. Is the USB3343 really faulty? If it is not faulty, can it be optimized to not display error frames? If the USB3343 is indeed faulty, what commands can be used to test and confirm that it is faulty?

ataradov, 2024-11-19:
Why do you want to hide them? They are representation of what happens on the bus. If you probe it with an oscilloscope you will see that bouncing too.

blueoce, 2024-11-19:
I disagree with the statement that replacing the chip is not helpful. It really did work after the replacement, I'm not lying to you。It is possible that some PHYs have slight manufacturing differences and are less sensitive to the noise.I think this is the real reason.

ataradov, 2024-11-19:
Well, you can continue to replace them if you want. But if anything, you are getting a worse deal. I personally would like to observe the real bus behavior.

I feel like you are missing the point of this tool or need something else for your use case.

stappersg, 2024-11-19:
On Tue, Nov 19, 2024 at 09:00:47AM -0800, Alex Taradov wrote:
>
> I feel like you are missing the point of this tool or need something else for your use case.
>

Act upon feeling and close this issue.

(Do known that closed issues can updated with information
as "Why do you want to hide the noise that does exist?")

Groeten
Geert Stappers
--
Silence is hard to parse

Closed 2024-11-19.

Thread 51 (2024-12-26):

Suggestions on BOM, PCB layout

Basilisvirus, 2024-12-26:
I will replicate this open source project soon. I am looking at the files right now and I would like a feedback from the suggestions Im making :)

1. For easier hand-soldering, without the need of a hot air station I suggest IC4 to have a large via hole in the middle of it:
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

This way the middle pad can be soldered from the bottom side by filling it with solder.
Be careful: make sure you slowly pour solder in the hole (start pouring solder to the side of the hole and wait for it get hot enough so that the solder will slow in on its own) and that the solder has "spourted" inside the hole on its own, to make sure the solder actually touched the pad and it didnt just cover the hole.

2. For mouser.com, IC6 (DSC6101CI2A-026.0000) is obsolete:
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

I think DSC6003MI2B-026.0000 is a good replacement. It is also smaller in size (VFLGA-4 footprint) , which means less load capacitance, easier to solder on the pre-existing pad without how air since the SMD pads now stick out.:
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

3. Same case for DSC6101CI2A-024.0000:
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
The DSC6001HI2B-024.0000 (VFLGA-4 footprint as well)  looks like a good replacement. Its smaller and the pads (again) stick out, so easier to solder with hand soldering iron.

4. This doesnt matter really, for the frequencies and length of the traces, but you will have impedance mismatch when the copper changes width, to the places where I point the arrows. A solution to that is to make the width not change so much, aka make zones around the pads:
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
This happens in some other places on the board.

5. This GND copper does not have vias close to it. So it might as well act as a floating copper and is a conductor for noise to get from one trace to another. Two solutions here. Either let enough space for GND vias or place the coppers close enough so that no GND copper will get there.
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
I applied the second fix for example:
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

6. I didnt see any instruction to order the PCB in 1mm instead of 1.55mm FR4. I guess 1mm will behave better, as the two layers will be closer. For that reason, I am mainly concerned about USB impedance. based on your USB D+/D- distance and trace thickness, the impedance of the USB differential data lines is 136.64Ω on 1mm PCB, this increases to 147Ω if 1.55mm FR4 is used.
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

(I will add new suggestions as I check more stuff. Let me know if I am wrong somewhere)

ataradov, 2024-12-26:
The hole is up to you. The IC is small and reasonably easy to solder by hand as it is.
None of the PCB stuff really matters, you can do it if it makes you sleep better.
And for the crystals, there is already multiple discussions with replacements from LCSD. The footprint universal, there are dozens of possible alternatives.

stappersg, 2024-12-27:
On Thu, Dec 26, 2024 at 07:28:56AM -0800, Christianidis Vasileios wrote:
> Closed #51 as completed.

For the PCB-layout, Yes.

For the Bill Of Materials change, hope I to see a merge request.

Groeten
Geert Stappers
--
Silence is hard to parse

ataradov, 2024-12-27:
I'm not going to accept merge requests. I need this repo to  match what I have. Different people will have access to the different parts and it is impossible to accommodate everyone. Plus things change over time. If you are building this, substitutions like that should be easy anyway.

Basilisvirus, 2024-12-28:
Agree with ataradov. Since he is so active on the issues, if you need any clarification about the BOM, one might as well raise an issue for it. Changing BOM will mean that ataradov will need to re-solder stuff and change things. This takes time and effort.

If anyone manages anything better they can make an issue, fork the project on their github and make the desired changes.

Closed 2024-12-26.

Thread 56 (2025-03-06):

Logging of CDC data fails

WillemOuwerkerk, 2025-03-06:
Hi Alex,

I can log the SETUP process of my CDC interface perfectly.
When i do an attempt to log the data sent when the connection is setup i see nothing.
Can you give me a clue of how to do that?
My current system is Windows 10 & Wireshark using the sniffer directly.

Kind regards,
Willem.

WillemOuwerkerk, 2025-03-06:
Yes, here is my last one made. This version gives showed transmitted dat on earlyer logs...

[usb-xs-6c.pcapng.gz](https://github.com/user-attachments/files/19111945/usb-xs-6c.pcapng.gz)

WillemOuwerkerk, 2025-03-06:
Hi Alex,
Yes that is part of the startup message. This version sends the characters one by one.
But any keystrokes after that are not shown.
How can i remove the IN/NAK pairs, i can try to find it out myself if it's to much trouble.

ataradov, 2025-03-06:
In the settings there is an option to fold empty frames, set it. Although I see occasional messages that empty frames are folded. If you have it set to fold, then something strange is going on. If you have folding disabled, then those sporadic messages are likely a software bug and I'll have to look into it.

As far as messages not showing, I don't see how they can disappear like this. Do you actually see the characters on the other side? What happens when you close the port? Do you see set line state/coding frames? They should happen when the port is closed.

ataradov, 2025-03-06:
Ok, I think you have folding enabled, but your host is very good at scheduling transfers. Right now there is a limit of 128 packets per frame, and your host schedules 136, so the folding stops.

If you can build the binary, then change FOLD_BUF_SIZE from 128 to 200 in capture.c and recompile it. Otherwise, I'll build new binaries later today.

This would explain why folding does not work and it will make the log much cleaner. But it would not explain the missing data. I think it is really missing, so if you actually see the bytes on the other side, but not in the log, we'll have to look deeper into that after we can get captures with folding working.

ataradov, 2025-03-06:
I've updated the binaries. Folding should work now.  Do a new capture. The logs will have less spam.

WillemOuwerkerk, 2025-03-07:
This is my last log

[usb-xs-06e.pcapng.gz](https://github.com/user-attachments/files/19123214/usb-xs-06e.pcapng.gz)

Can you tell me how to put folding from the wireshark call of the sniffer?

ataradov, 2025-03-07:
Is this with the new binary? Double check that it actually is. This really looks like the old behavior. The folding is enabled, since you can see messages about folding at the beginning, but most of the stuff is not folded because there are more than 128 packers between SOFs.

Do other things I described - capture closing of the port to see if you get set line state and line coding messages.

What is the device? Is this CDC implemented on an MCU or a serial to USB adapter?

I would try with just an unconnected USB-to-serial adapter just to get a more controlled test.

ataradov, 2025-03-07:
It should be "-s fs". The device is Full-Speed, so the log contains just noise.

WillemOuwerkerk, 2025-03-07:
Yes sorry, i just discovered that too. This one looks nice.

[usb-xs03e.zip](https://github.com/user-attachments/files/19129988/usb-xs03e.zip)

ataradov, 2025-03-07:
Ok, this looks seems to at least end at the same place at as the pcapcmd one with "FORTH FORTH EXTRA ONLY : FORTH ) OK.0
@)".

ataradov, 2025-03-07:
And folding now works as expected. You can see all the empty frames go away.

WillemOuwerkerk, 2025-03-07:
Yes Alex, this looks a lot better. Also the data communication is captured.
Do you have any idea why wireshark still uses the old sniffer version?

ataradov, 2025-03-07:
You probably did not put it at the right path. Go to Help->About Wireshark->Folders and check "Global Extcap path". This is the place where the binary should be located.

WillemOuwerkerk, 2025-03-08:
Hi Alex,

Done now, everything is working smootly.
Now a can study the data stream en try to improve & optimise the cdc-driver i use.

Thanks again.
Willem

ataradov, 2025-03-08:
Closing the issue then.

Closed 2025-03-08.

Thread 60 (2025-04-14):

Frequent hardware buffer overflow message in sniffer

WillemOuwerkerk, 2025-04-14:
Hi Alex,

When sending large chunks of data over my CDC interface i frequently
get the message below. The data arrived correctly but the sniffer does
not show parts of it. Can you tell me if this can be solved?

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

Kind regards,
Willem Ouwerkerk

WillemOuwerkerk, 2025-04-14:
Removed de external HUB for measurements and now it's ok, thanks Alex.

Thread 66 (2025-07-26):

CY7C68013A-56PVXCT is obsolete

haldark, 2025-07-26:
Hello,

CY7C68013A-56PVXCT is obsolete and out of inventory in all major reputed distributors (Mouser, Digikey, Farnell, Arrow). Infinion also does not mention a replacement part, which is kind of surprising.

Without this major part unavailable, this project will be impossible to create.

I would appreciate if anybody can point me to a footprint compatible replacement part.

Best Regards,

ataradov, 2025-08-04:
For now I just wait until some better devices comes along. CBM9002A will be here for a very long time, and I expect availability to increase as CY device goes away. Dumping data into PC is a thing that is useful in many projects, so I'm actively looking for a solution. I'm waiting for a good tool-less design, but this may not happen, and then there are a few options:
1. The most direct is probably CH569W. But it is subject to the same issue as CBM9002A - only available from China, so availability is unpredictable.
2. Just use FPGA. I have a Verilog implementation of the USB HS peripheral. This was actually don for V1 of this project. So, the whole system could be 2 x USB PHY, FPGA and either really small external MCU, or internal RISC-V core. Internal core is attractive, but takes up a lot of memory blocks, so requires bigger FPGA just for that. This is not likely to be tool-less. There are Gowin FPGAs with embedded hard ARM core, but those are rarely actually available on the market.
3. Newer MCUs finally start to include good parallel capture interface.  STMH5/H7 have PSSI peripheral, which seems to be good. I will be experimenting with it in the current project I'm working on. But unfortunately, STMH5/H7 need USB PHY to make USB HS work and this requires at least 100 pin package.
4. I know for sure that this can be made to with with Atmel SAM E70. It has parallel capture interface that I know can do 60 MHz capture. It will be toll-less too. But it needs 100 pin package, but at least no external PHY.

There are plenty of options, I'm just waiting until CY/CBM device availability really becomes an issue, and may be by that time some of the things above become available.

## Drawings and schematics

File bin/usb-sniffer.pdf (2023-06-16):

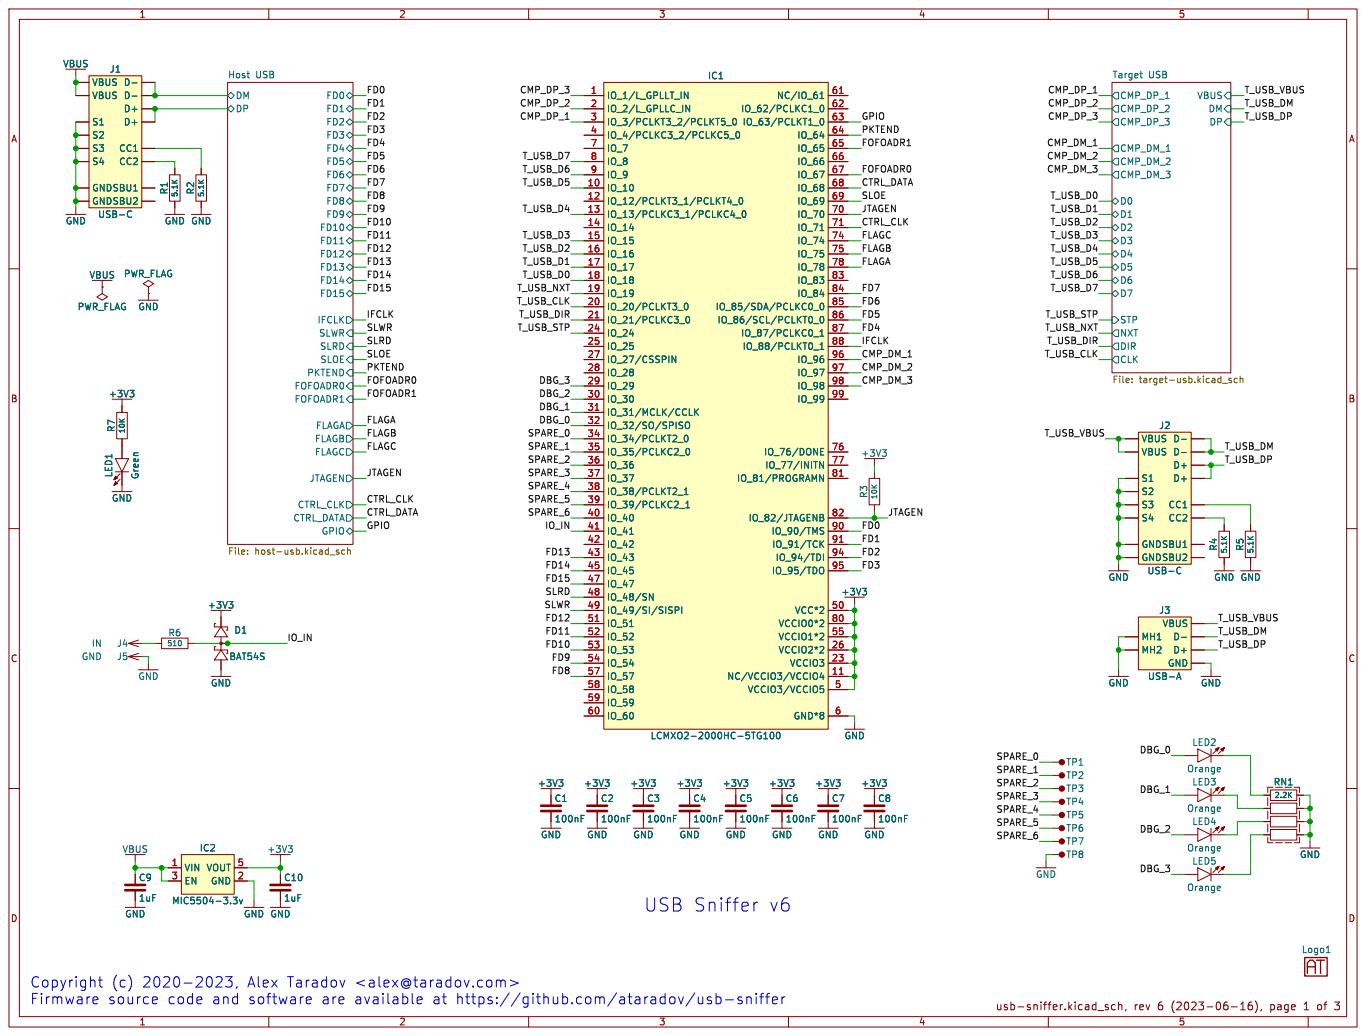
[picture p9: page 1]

SLWR
SLWR GPIO
File: target-usb.kicad_sch SLRD

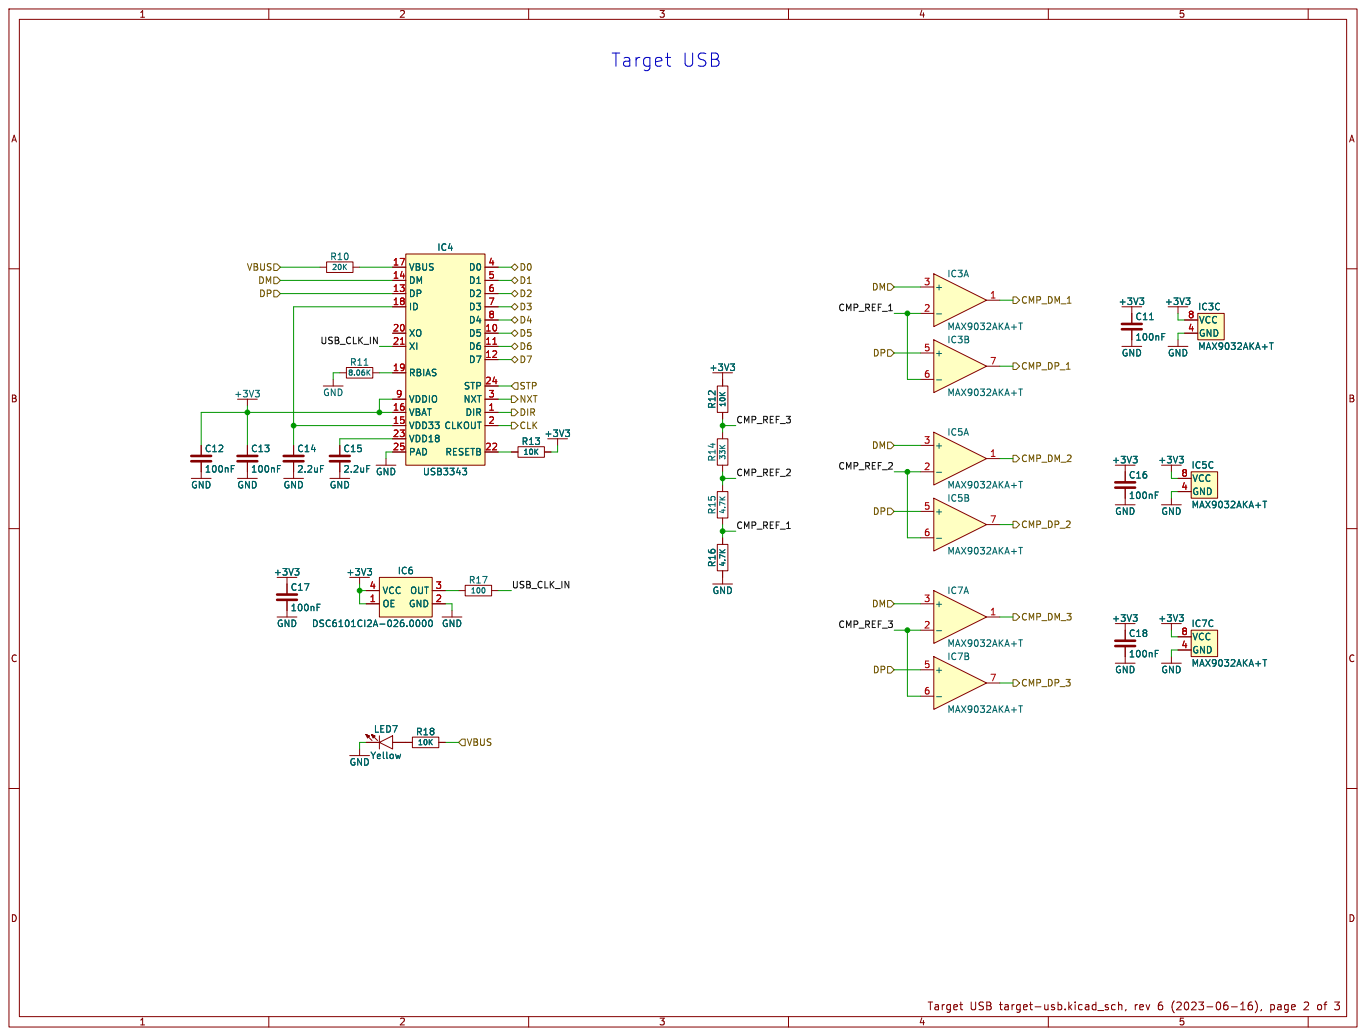
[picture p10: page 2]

+3V3 CMP_DP_2 STP D0 D2 D3 D1 NXT D6 CLK DIR

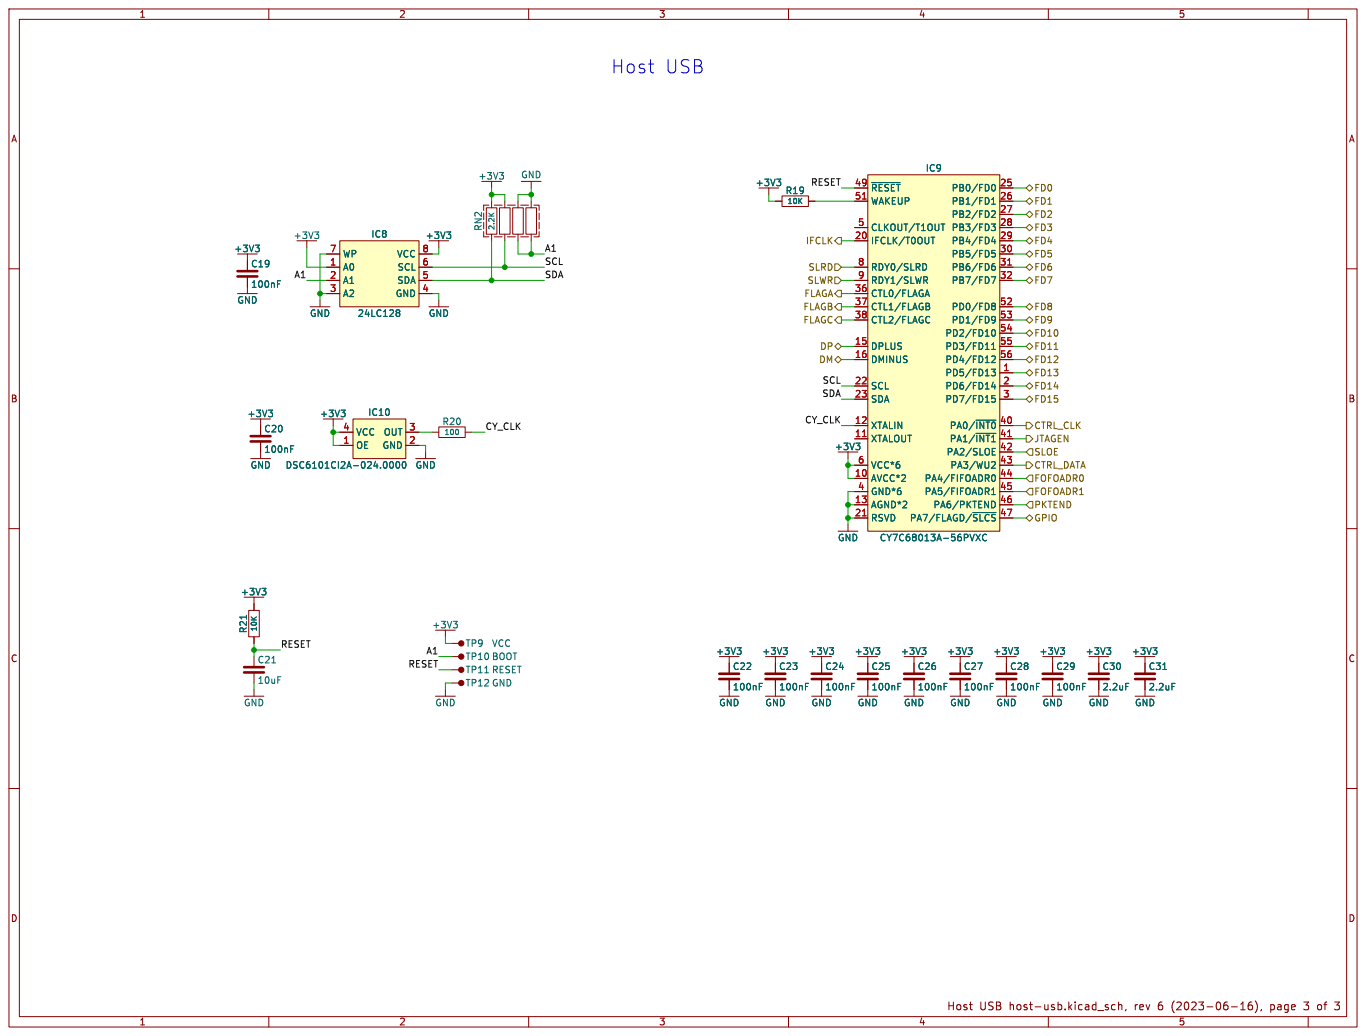
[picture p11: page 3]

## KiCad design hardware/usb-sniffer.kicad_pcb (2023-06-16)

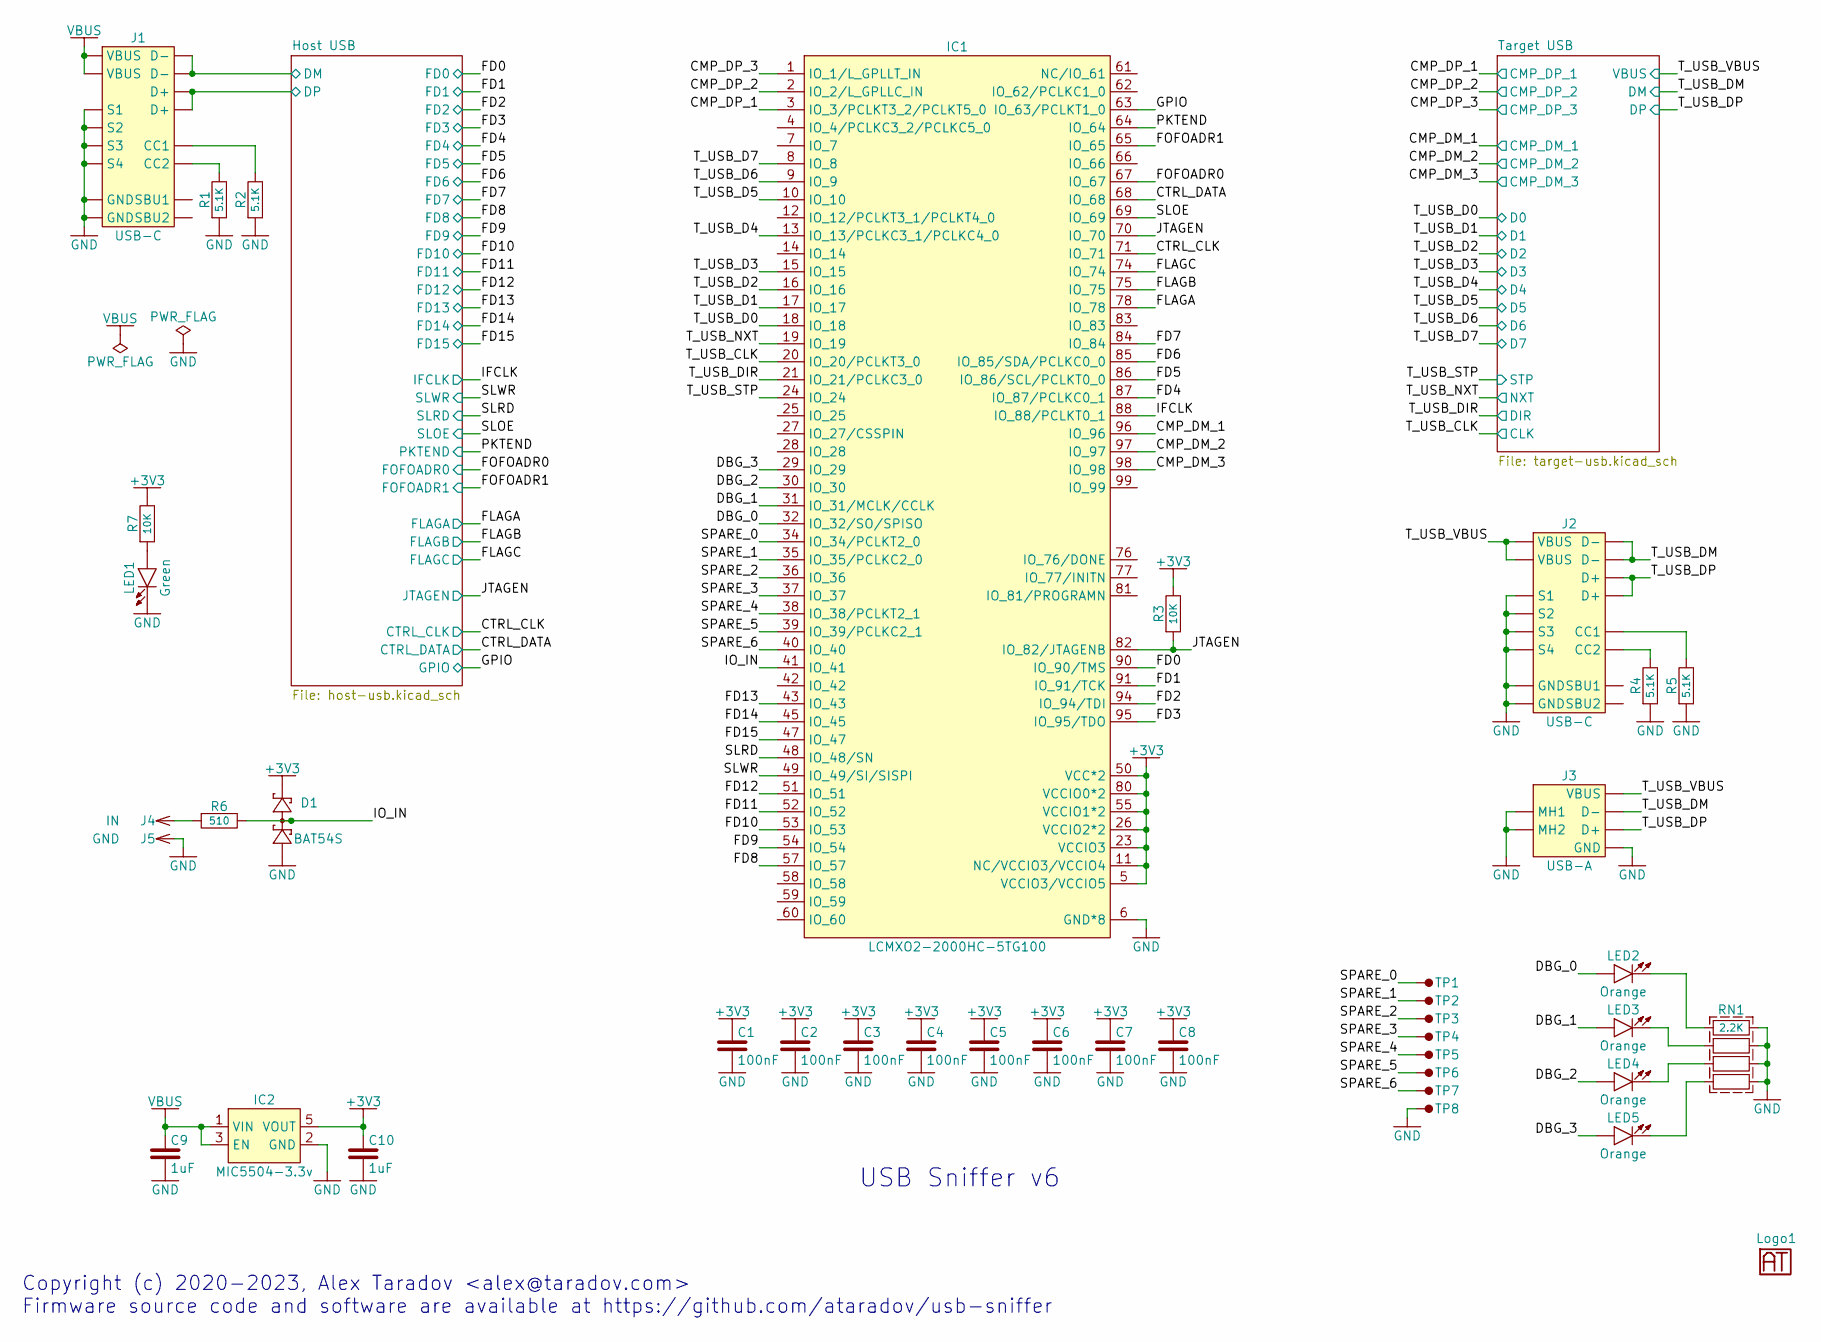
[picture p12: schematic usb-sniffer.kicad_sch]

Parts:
C1, C2, C3, C4, C5, C6, C7, C8: 100nF; 0603
C9, C10: 1uF; 0603
D1: BAT54S; SOT-23
IC1: LCMXO2-2000HC-5TG100; TQFP-100-0.5mm
IC2: MIC5504-3.3v; SOT-23-5
J1, J2: USB-C
J3: USB-A; USB-A-Slots
J4: IN; Pin-2.54mm
J5: GND; Pin-2.54mm
LED1: Green; 0603
LED2, LED3, LED4, LED5: Orange; 0603
Logo1: Logo; Logo-Small
R1, R2, R4, R5: 5.1K; 0603
R3, R7: 10K; 0603
R6: 510; 0603
RN1: 2.2K; 0603x4
TP1, TP2, TP3, TP4, TP5, TP6, TP7, TP8: TestPoint-1.27mm-Small

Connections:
+3V3: C1.2, C2.2, C3.2, C4.2, C5.2, C6.2, C7.2, C8.2, C10.2, D1.2, IC1.5 (VCCIO3/VCCIO5), IC1.11 (NC/VCCIO3/VCCIO4), IC1.23 (VCCIO3), IC1.26 (VCCIO2*2), IC1.46 (VCCIO2), IC1.50 (VCC*2), IC1.55 (VCCIO1*2), IC1.73 (VCCIO1), IC1.80 (VCCIO0*2), IC1.93 (VCCIO0), IC1.100 (VCC), IC2.5 (VOUT), R3.2, R7.2; also elsewhere on the board
/CMP_DM_1: IC1.96 (IO_96); also elsewhere on the board
/CMP_DM_2: IC1.97 (IO_97); also elsewhere on the board
/CMP_DM_3: IC1.98 (IO_98); also elsewhere on the board
/CMP_DP_1: IC1.3 (IO_3/PCLKT3_2/PCLKT5_0); also elsewhere on the board
/CMP_DP_2: IC1.2 (IO_2/L_GPLLC_IN); also elsewhere on the board
/CMP_DP_3: IC1.1 (IO_1/L_GPLLT_IN); also elsewhere on the board
/CTRL_CLK: IC1.71 (IO_71); also elsewhere on the board
/CTRL_DATA: IC1.68 (IO_68); also elsewhere on the board
/DBG_0: IC1.32 (IO_32/SO/SPISO), LED2.1 (A)
/DBG_1: IC1.31 (IO_31/MCLK/CCLK), LED3.1 (A)
/DBG_2: IC1.30 (IO_30), LED4.1 (A)
/DBG_3: IC1.29 (IO_29), LED5.1 (A)
/FD0: IC1.90 (IO_90/TMS); also elsewhere on the board
/FD1: IC1.91 (IO_91/TCK); also elsewhere on the board
/FD2: IC1.94 (IO_94/TDI); also elsewhere on the board
/FD3: IC1.95 (IO_95/TDO); also elsewhere on the board
/FD4: IC1.87 (IO_87/PCLKC0_1); also elsewhere on the board
/FD5: IC1.86 (IO_86/SCL/PCLKT0_0); also elsewhere on the board
/FD6: IC1.85 (IO_85/SDA/PCLKC0_0); also elsewhere on the board
/FD7: IC1.84 (IO_84); also elsewhere on the board
/FD8: IC1.57 (IO_57); also elsewhere on the board
/FD9: IC1.54 (IO_54); also elsewhere on the board
/FD10: IC1.53 (IO_53); also elsewhere on the board
/FD11: IC1.52 (IO_52); also elsewhere on the board
/FD12: IC1.51 (IO_51); also elsewhere on the board
/FD13: IC1.43 (IO_43); also elsewhere on the board
/FD14: IC1.45 (IO_45); also elsewhere on the board
/FD15: IC1.47 (IO_47); also elsewhere on the board
/FLAGA: IC1.78 (IO_78); also elsewhere on the board
/FLAGB: IC1.75 (IO_75); also elsewhere on the board
/FLAGC: IC1.74 (IO_74); also elsewhere on the board
/FOFOADR0: IC1.67 (IO_67); also elsewhere on the board
/FOFOADR1: IC1.65 (IO_65); also elsewhere on the board
/GPIO: IC1.63 (IO_63/PCLKT1_0); also elsewhere on the board
/Host USB/DM: J1.D-1 (D-), J1.D-2 (D-); also elsewhere on the board
/Host USB/DP: J1.D+1 (D+), J1.D+2 (D+); also elsewhere on the board
/IFCLK: IC1.88 (IO_88/PCLKT0_1); also elsewhere on the board
/IO_IN: D1.3, IC1.41 (IO_41), R6.2
/JTAGEN: IC1.70 (IO_70), IC1.82 (IO_82/JTAGENB), R3.1; also elsewhere on the board
/PKTEND: IC1.64 (IO_64); also elsewhere on the board
/SLOE: IC1.69 (IO_69); also elsewhere on the board
/SLRD: IC1.48 (IO_48/SN); also elsewhere on the board
/SLWR: IC1.49 (IO_49/SI/SISPI); also elsewhere on the board
/SPARE_0: IC1.34 (IO_34/PCLKT2_0), TP1.1
/SPARE_1: IC1.35 (IO_35/PCLKC2_0), TP2.1
/SPARE_2: IC1.36 (IO_36), TP3.1
/SPARE_3: IC1.37 (IO_37), TP4.1
/SPARE_4: IC1.38 (IO_38/PCLKT2_1), TP5.1
/SPARE_5: IC1.39 (IO_39/PCLKC2_1), TP6.1
/SPARE_6: IC1.40 (IO_40), TP7.1
/T_USB_CLK: IC1.20 (IO_20/PCLKT3_0); also elsewhere on the board
/T_USB_D0: IC1.18 (IO_18); also elsewhere on the board
/T_USB_D1: IC1.17 (IO_17); also elsewhere on the board
/T_USB_D2: IC1.16 (IO_16); also elsewhere on the board
/T_USB_D3: IC1.15 (IO_15); also elsewhere on the board
/T_USB_D4: IC1.13 (IO_13/PCLKC3_1/PCLKC4_0); also elsewhere on the board
/T_USB_D5: IC1.10 (IO_10); also elsewhere on the board
/T_USB_D6: IC1.9 (IO_9); also elsewhere on the board
/T_USB_D7: IC1.8 (IO_8); also elsewhere on the board
/T_USB_DIR: IC1.21 (IO_21/PCLKC3_0); also elsewhere on the board
/T_USB_DM: J2.D-1 (D-), J2.D-2 (D-), J3.D-; also elsewhere on the board
/T_USB_DP: J2.D+1 (D+), J2.D+2 (D+), J3.D+; also elsewhere on the board
/T_USB_NXT: IC1.19 (IO_19); also elsewhere on the board
/T_USB_STP: IC1.24 (IO_24); also elsewhere on the board
/T_USB_VBUS: J2.VBUS1 (VBUS), J2.VBUS2 (VBUS), J3.VBUS; also elsewhere on the board
GND: C1.1, C2.1, C3.1, C4.1, C5.1, C6.1, C7.1, C8.1, C9.1, C10.1, D1.1, IC1.6 (GND*8), IC1.22 (GND), IC1.33 (GND), IC1.44 (GND), IC1.56 (GND), IC1.72 (GND), IC1.79 (GND), IC1.92 (GND), IC2.2 (GND), J1.GND1 (GND), J1.GND2 (GND), J1.S1, J1.S2, J1.S3, J1.S4, J2.GND1 (GND), J2.GND2 (GND), J2.S1, J2.S2, J2.S3, J2.S4, J3.GND, J3.MH1, J3.MH2, J5.1, LED1.2 (K), R1.1, R2.1, R4.1, R5.1, RN1.5, RN1.6, RN1.7, RN1.8, TP8.1; also elsewhere on the board
unnamed: J1.CC1, R2.2
unnamed: J1.CC2, R1.2
unnamed: J2.CC1, R5.2
unnamed: J2.CC2, R4.2
unnamed: J4.1, R6.1
unnamed: LED1.1 (A), R7.1
unnamed: LED2.2 (K), RN1.1
unnamed: LED3.2 (K), RN1.2
unnamed: LED4.2 (K), RN1.3
unnamed: LED5.2 (K), RN1.4
VBUS: C9.2, IC2.1 (VIN), IC2.3 (EN), J1.VBUS1 (VBUS), J1.VBUS2 (VBUS)

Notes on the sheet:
Copyright (c) 2020-2023, Alex Taradov <alex@taradov.com> Firmware source code and software are available at https://github.com/ataradov/usb-sniffer
USB Sniffer v6

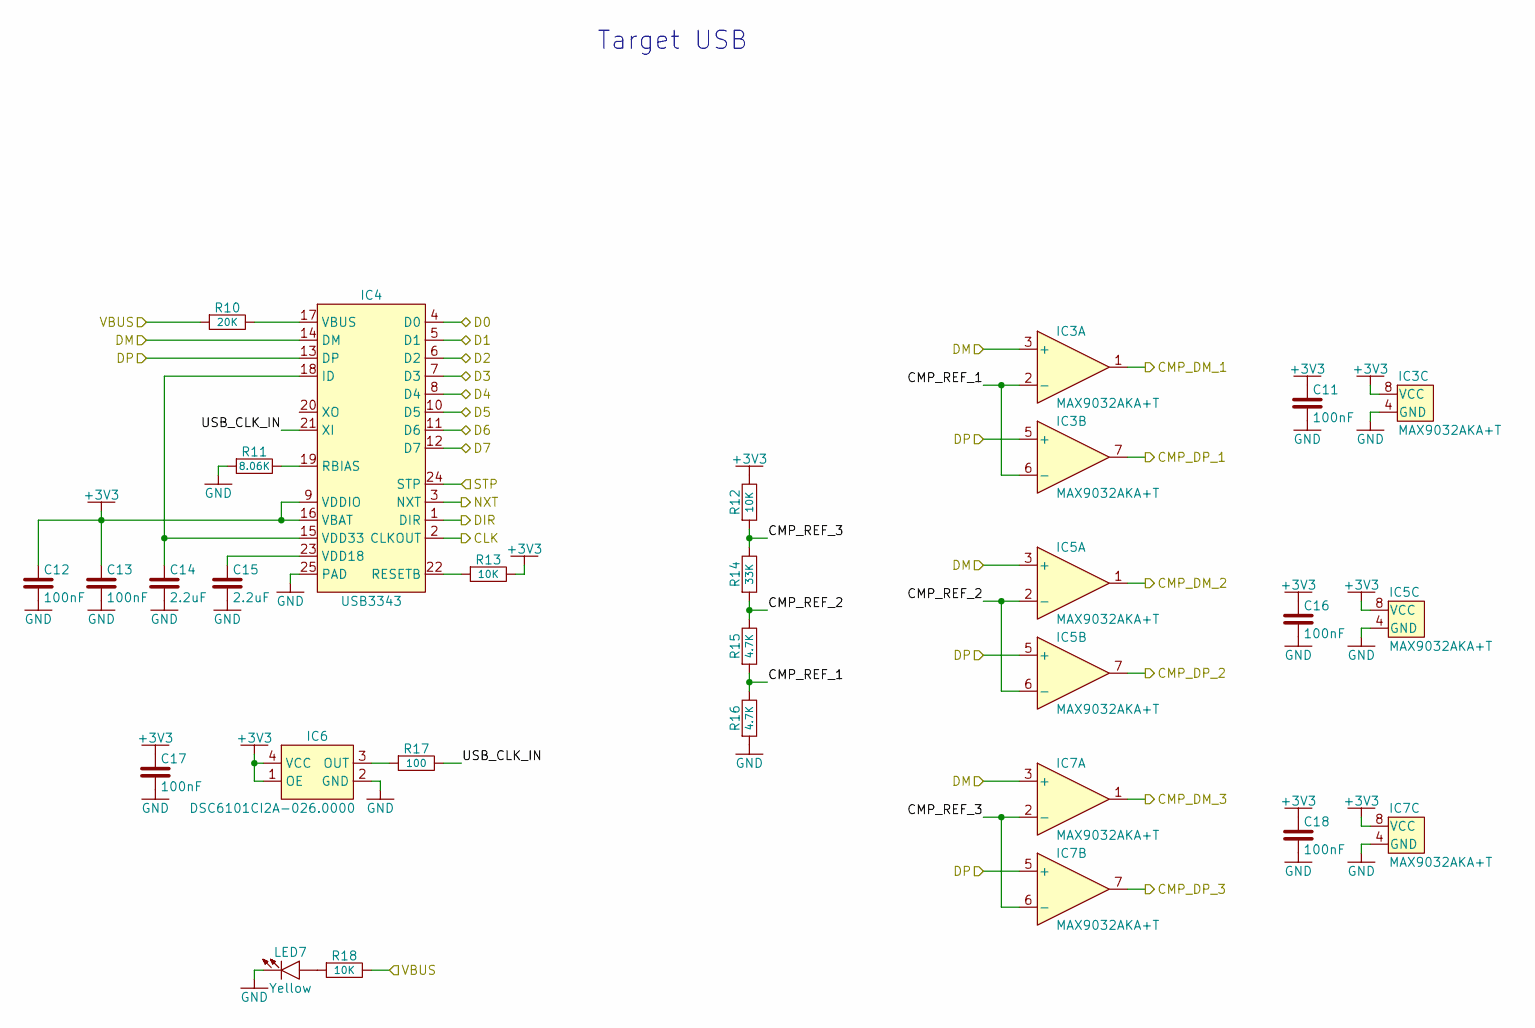
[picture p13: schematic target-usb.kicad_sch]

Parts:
C11, C12, C13, C16, C17, C18: 100nF; 0603
C14, C15: 2.2uF; 0603
IC3, IC5, IC7: MAX9032AKA+T; SOT-23-8
IC4: USB3343; QFN-24-0.5mm
IC6: DSC6101CI2A-026.0000; CDFN-4-3.2x2.5mm
LED7: Yellow; 0603
R10: 20K; 0603
R11: 8.06K; 0603
R12, R13, R18: 10K; 0603
R14: 33K; 0603
R15, R16: 4.7K; 0603
R17: 100; 0603

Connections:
+3V3: C11.2, C12.2, C13.2, C16.2, C17.2, C18.2, IC3.8 (VCC), IC4.9 (VDDIO), IC4.16 (VBAT), IC5.8 (VCC), IC6.1 (OE), IC6.4 (VCC), IC7.8 (VCC), R12.2, R13.2; also elsewhere on the board
/CMP_DM_1: IC3.1; also elsewhere on the board
/CMP_DM_2: IC5.1; also elsewhere on the board
/CMP_DM_3: IC7.1; also elsewhere on the board
/CMP_DP_1: IC3.7; also elsewhere on the board
/CMP_DP_2: IC5.7; also elsewhere on the board
/CMP_DP_3: IC7.7; also elsewhere on the board
/T_USB_CLK: IC4.2 (CLKOUT); also elsewhere on the board
/T_USB_D0: IC4.4 (D0); also elsewhere on the board
/T_USB_D1: IC4.5 (D1); also elsewhere on the board
/T_USB_D2: IC4.6 (D2); also elsewhere on the board
/T_USB_D3: IC4.7 (D3); also elsewhere on the board
/T_USB_D4: IC4.8 (D4); also elsewhere on the board
/T_USB_D5: IC4.10 (D5); also elsewhere on the board
/T_USB_D6: IC4.11 (D6); also elsewhere on the board
/T_USB_D7: IC4.12 (D7); also elsewhere on the board
/T_USB_DIR: IC4.1 (DIR); also elsewhere on the board
/T_USB_DM: IC3.3 (+), IC4.14 (DM), IC5.3 (+), IC7.3 (+); also elsewhere on the board
/T_USB_DP: IC3.5 (+), IC4.13 (DP), IC5.5 (+), IC7.5 (+); also elsewhere on the board
/T_USB_NXT: IC4.3 (NXT); also elsewhere on the board
/T_USB_STP: IC4.24 (STP); also elsewhere on the board
/T_USB_VBUS: R10.1, R18.2; also elsewhere on the board
/Target USB/CMP_REF_1: IC3.2 (-), IC3.6 (-), R15.1, R16.2
/Target USB/CMP_REF_2: IC5.2 (-), IC5.6 (-), R14.1, R15.2
/Target USB/CMP_REF_3: IC7.2 (-), IC7.6 (-), R12.1, R14.2
/Target USB/USB_CLK_IN: IC4.21 (XI), R17.2
GND: C11.1, C12.1, C13.1, C14.1, C15.1, C16.1, C17.1, C18.1, IC3.4 (GND), IC4.25 (PAD), IC5.4 (GND), IC6.2 (GND), IC7.4 (GND), LED7.2 (K), R11.1, R16.1; also elsewhere on the board
unnamed: C14.2, IC4.15 (VDD33), IC4.18 (ID)
unnamed: IC4.19 (RBIAS), R11.2
unnamed: IC4.22 (RESETB), R13.1
unnamed: IC4.17 (VBUS), R10.2
unnamed: C15.2, IC4.23 (VDD18)
unnamed: IC6.3 (OUT), R17.1
unnamed: LED7.1 (A), R18.1

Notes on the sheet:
Target USB

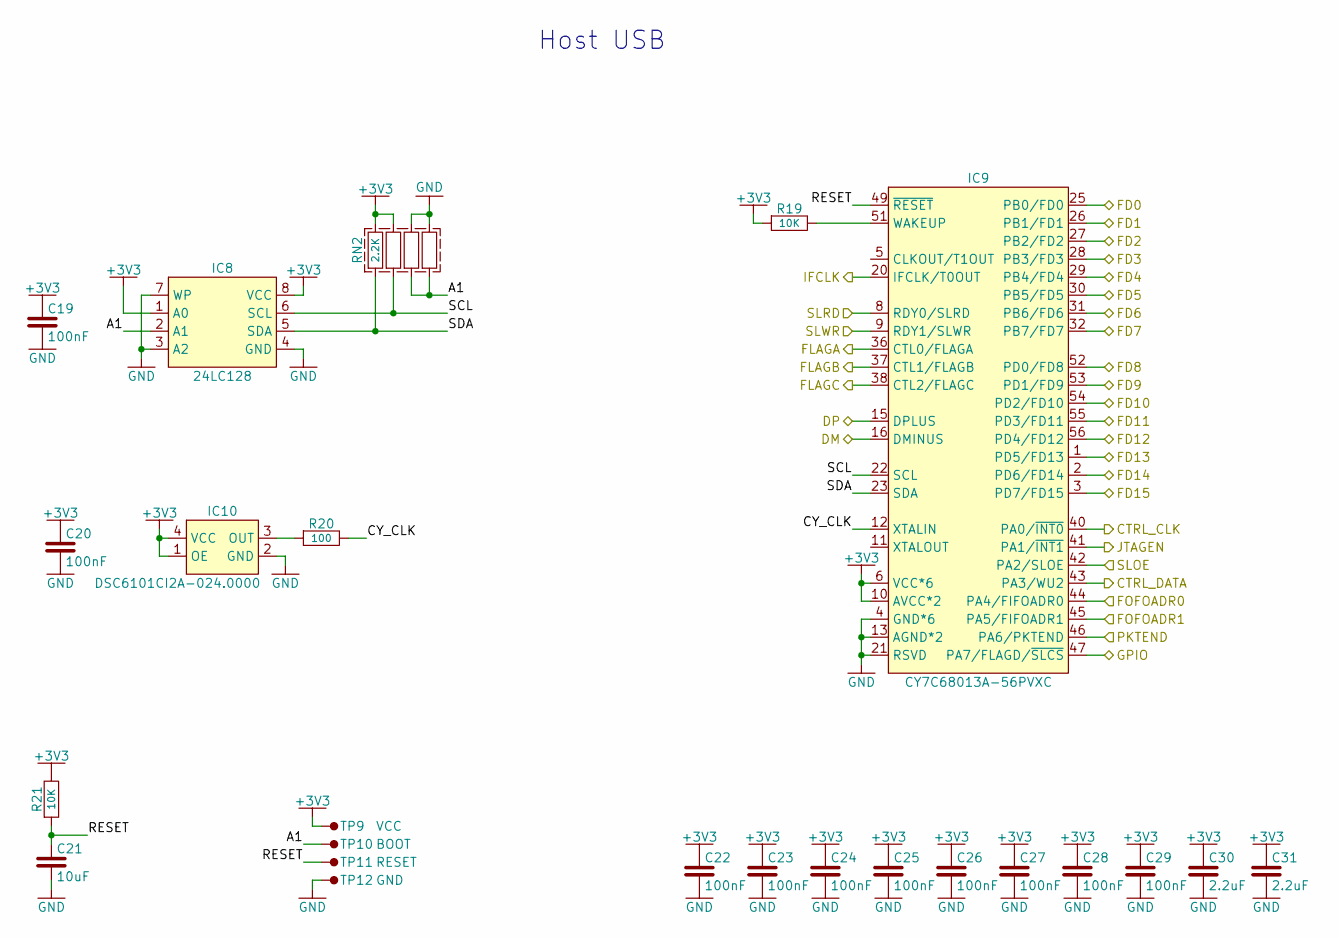
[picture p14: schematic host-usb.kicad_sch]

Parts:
C19, C20, C22, C23, C24, C25, C26, C27, C28, C29: 100nF; 0603
C21: 10uF; 0603
C30, C31: 2.2uF; 0603
IC8: 24LC128; SO-8
IC9: CY7C68013A-56PVXC; SSOP-56-0.635mm
IC10: DSC6101CI2A-024.0000; CDFN-4-3.2x2.5mm
R19, R21: 10K; 0603
R20: 100; 0603
RN2: 2.2K; 0603x4
TP9: VCC; TestPoint-1.27mm
TP10: BOOT; TestPoint-1.27mm
TP11: RESET; TestPoint-1.27mm
TP12: GND; TestPoint-1.27mm

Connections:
+3V3: C19.2, C20.2, C22.2, C23.2, C24.2, C25.2, C26.2, C27.2, C28.2, C29.2, C30.2, C31.2, IC8.1 (A0), IC8.8 (VCC), IC9.6 (VCC*6), IC9.10 (AVCC*2), IC9.14 (AVCC), IC9.18 (VCC), IC9.24 (VCC), IC9.34 (VCC), IC9.39 (VCC), IC9.50 (VCC), IC10.1 (OE), IC10.4 (VCC), R19.1, R21.2, RN2.7, RN2.8, TP9.1; also elsewhere on the board
/CTRL_CLK: IC9.40 (PA0/~INT0); also elsewhere on the board
/CTRL_DATA: IC9.43 (PA3/WU2); also elsewhere on the board
/FD0: IC9.25 (PB0/FD0); also elsewhere on the board
/FD1: IC9.26 (PB1/FD1); also elsewhere on the board
/FD2: IC9.27 (PB2/FD2); also elsewhere on the board
/FD3: IC9.28 (PB3/FD3); also elsewhere on the board
/FD4: IC9.29 (PB4/FD4); also elsewhere on the board
/FD5: IC9.30 (PB5/FD5); also elsewhere on the board
/FD6: IC9.31 (PB6/FD6); also elsewhere on the board
/FD7: IC9.32 (PB7/FD7); also elsewhere on the board
/FD8: IC9.52 (PD0/FD8); also elsewhere on the board
/FD9: IC9.53 (PD1/FD9); also elsewhere on the board
/FD10: IC9.54 (PD2/FD10); also elsewhere on the board
/FD11: IC9.55 (PD3/FD11); also elsewhere on the board
/FD12: IC9.56 (PD4/FD12); also elsewhere on the board
/FD13: IC9.1 (PD5/FD13); also elsewhere on the board
/FD14: IC9.2 (PD6/FD14); also elsewhere on the board
/FD15: IC9.3 (PD7/FD15); also elsewhere on the board
/FLAGA: IC9.36 (CTL0/FLAGA); also elsewhere on the board
/FLAGB: IC9.37 (CTL1/FLAGB); also elsewhere on the board
/FLAGC: IC9.38 (CTL2/FLAGC); also elsewhere on the board
/FOFOADR0: IC9.44 (PA4/FIFOADR0); also elsewhere on the board
/FOFOADR1: IC9.45 (PA5/FIFOADR1); also elsewhere on the board
/GPIO: IC9.47 (PA7/FLAGD/~SLCS); also elsewhere on the board
/Host USB/A1: IC8.2 (A1), RN2.3, RN2.4, TP10.1
/Host USB/CY_CLK: IC9.12 (XTALIN), R20.2
/Host USB/DM: IC9.16 (DMINUS); also elsewhere on the board
/Host USB/DP: IC9.15 (DPLUS); also elsewhere on the board
/Host USB/RESET: C21.2, IC9.49 (~RESET), R21.1, TP11.1
/Host USB/SCL: IC8.6 (SCL), IC9.22 (SCL), RN2.2
/Host USB/SDA: IC8.5 (SDA), IC9.23 (SDA), RN2.1
/IFCLK: IC9.20 (IFCLK/T0OUT); also elsewhere on the board
/JTAGEN: IC9.41 (PA1/~INT1); also elsewhere on the board
/PKTEND: IC9.46 (PA6/PKTEND); also elsewhere on the board
/SLOE: IC9.42 (PA2/SLOE); also elsewhere on the board
/SLRD: IC9.8 (RDY0/SLRD); also elsewhere on the board
/SLWR: IC9.9 (RDY1/SLWR); also elsewhere on the board
GND: C19.1, C20.1, C21.1, C22.1, C23.1, C24.1, C25.1, C26.1, C27.1, C28.1, C29.1, C30.1, C31.1, IC8.3 (A2), IC8.4 (GND), IC8.7 (WP), IC9.4 (GND*6), IC9.7 (GND), IC9.13 (AGND*2), IC9.17 (AGND), IC9.19 (GND), IC9.21 (RSVD), IC9.33 (GND), IC9.35 (GND), IC9.48 (GND), IC10.2 (GND), RN2.5, RN2.6, TP12.1; also elsewhere on the board
unnamed: IC9.51 (WAKEUP), R19.2
unnamed: IC10.3 (OUT), R20.1

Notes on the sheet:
Host USB

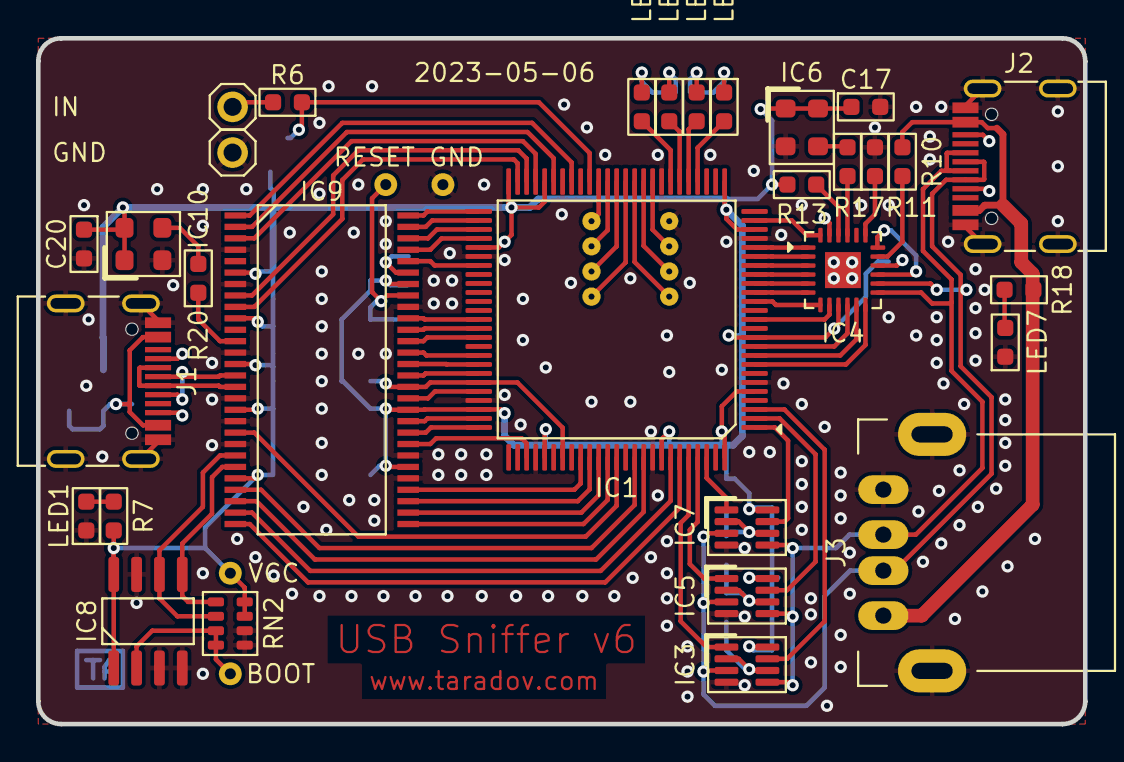
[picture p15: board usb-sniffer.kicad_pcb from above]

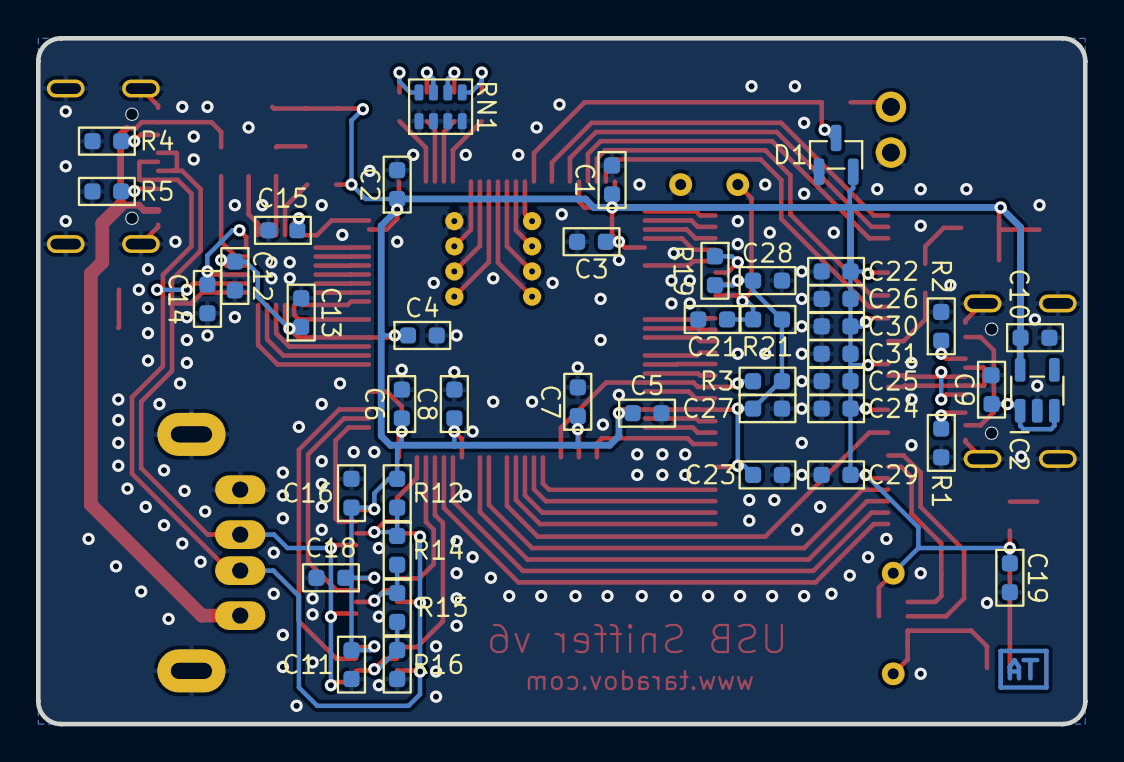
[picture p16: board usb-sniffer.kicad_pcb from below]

Board: 2 copper layers, 58.2 x 38.1 mm, 87 parts (44 on the bottom side), 96 nets.

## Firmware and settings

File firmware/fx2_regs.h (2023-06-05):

// SPDX-License-Identifier: BSD-3-Clause
// Copyright (c) 2023, Alex Taradov <alex@taradov.com>. All rights reserved.

#ifndef _FX2_REGS_H_
#define _FX2_REGS_H_

/*- Includes ----------------------------------------------------------------*/
#include <stdint.h>

/*- Definitions -------------------------------------------------------------*/
#define REG(addr, name)			__xdata __at(addr) volatile uint8_t name
#define SFR_REG(addr, name)		__sfr   __at(addr) name
#define SFR_BIT(addr, name)		__sbit  __at(addr) name

#define SYNCDELAY			__asm nop; nop; nop; nop; nop; nop; __endasm
#define NOP				__asm nop; __endasm

#define MSB(x)				(((uint16_t)(x)) >> 8)
#define LSB(x)				(((uint16_t)(x)) & 0xff)

// Registers that Require a Synchronization Delay:
// FIFORESET FIFOPINPOLAR ECCCFG INPKTEND EPxBCH:L ECCRESET
// EPxFIFOPFH:L EPxAUTOINLENH:L ECC1B0 EPxFIFOCFG EPxGPIFFLGSEL ECC1B1
// PINFLAGSAB PINFLAGSCD ECC1B2 EPxFIFOIE EPxFIFOIRQ ECC2B0
// GPIFIE GPIFIRQ ECC2B1 UDMACRCH:L GPIFADRH:L ECC2B2
// GPIFTRIG EPxGPIFTRIG OUTPKTEND REVCTL GPIFTCB3 GPIFTCB2
// GPIFTCB1 GPIFTCB0

//-----------------------------------------------------------------------------
SFR_REG(0x80, IOA);
  SFR_BIT(0x80+0, IOA_0_b);
  SFR_BIT(0x80+1, IOA_1_b);
  SFR_BIT(0x80+2, IOA_2_b);
  SFR_BIT(0x80+3, IOA_3_b);
  SFR_BIT(0x80+4, IOA_4_b);
  SFR_BIT(0x80+5, IOA_5_b);
  SFR_BIT(0x80+6, IOA_6_b);
  SFR_BIT(0x80+7, IOA_7_b);
SFR_REG(0x81, SP);
SFR_REG(0x82, DPL0);
SFR_REG(0x83, DPH0);
SFR_REG(0x84, DPL1);
SFR_REG(0x85, DPH1);
SFR_REG(0x86, DPS);
  SFR_BIT(0x86+0, DPS_SEL_b);
SFR_REG(0x87, PCON);
  SFR_BIT(0x87+0, PCON_IDLE_b);
  SFR_BIT(0x87+7, PCON_SMOD0_b);
SFR_REG(0x88, TCON);
  SFR_BIT(0x88+0, TCON_IT0_b);
  SFR_BIT(0x88+1, TCON_IE0_b);
  SFR_BIT(0x88+2, TCON_IT1_b);
  SFR_BIT(0x88+3, TCON_IE1_b);
  SFR_BIT(0x88+4, TCON_TR0_b);
  SFR_BIT(0x88+5, TCON_TF0_b);
  SFR_BIT(0x88+6, TCON_TR1_b);
  SFR_BIT(0x88+7, TCON_TF1_b);
SFR_REG(0x89, TMOD);
  SFR_BIT(0x89+0, TMOD_M00_b);
  SFR_BIT(0x89+1, TMOD_M10_b);
  SFR_BIT(0x89+2, TMOD_CT0_b);
  SFR_BIT(0x89+3, TMOD_GATE0_b);
  SFR_BIT(0x89+4, TMOD_M01_b);
  SFR_BIT(0x89+5, TMOD_M11_b);
  SFR_BIT(0x89+6, TMOD_CT1_b);
  SFR_BIT(0x89+7, TMOD_GATE1_b);
SFR_REG(0x8a, TL0);
SFR_REG(0x8b, TL1);
SFR_REG(0x8c, TH0);
SFR_REG(0x8d, TH1);
SFR_REG(0x8e, CKCON);
  SFR_BIT(0x8e+0, CKCON_MD0_b);
  SFR_BIT(0x8e+1, CKCON_MD1_b);
  SFR_BIT(0x8e+2, CKCON_MD2_b);
  SFR_BIT(0x8e+3, CKCON_T0M_b);
  SFR_BIT(0x8e+4, CKCON_T1M_b);
  SFR_BIT(0x8e+5, CKCON_T2M_b);
SFR_REG(0x90, IOB);
  SFR_BIT(0x90+0, IOB_0_b);
  SFR_BIT(0x90+1, IOB_1_b);
  SFR_BIT(0x90+2, IOB_2_b);
  SFR_BIT(0x90+3, IOB_3_b);
  SFR_BIT(0x90+4, IOB_4_b);
  SFR_BIT(0x90+5, IOB_5_b);
  SFR_BIT(0x90+6, IOB_6_b);
  SFR_BIT(0x90+7, IOB_7_b);
SFR_REG(0x91, EXIF);
  SFR_BIT(0x91+4, EXIF_USBINT_b);
  SFR_BIT(0x91+5, EXIF_I2CINT_b);
  SFR_BIT(0x91+6, EXIF_IE4_b);
  SFR_BIT(0x91+7, EXIF_IE5_b);
SFR_REG(0x92, MPAGE);
SFR_REG(0x98, SCON0);
  SFR_BIT(0x98+0, SCON0_RI_b);
  SFR_BIT(0x98+1, SCON0_TI_b);
  SFR_BIT(0x98+2, SCON0_RB8_b);
  SFR_BIT(0x98+3, SCON0_TB8_b);
  SFR_BIT(0x98+4, SCON0_REN_b);
  SFR_BIT(0x98+5, SCON0_SM2_b);
  SFR_BIT(0x98+6, SCON0_SM1_b);
  SFR_BIT(0x98+7, SCON0_SM0_b);
SFR_REG(0x99, SBUF0);
SFR_REG(0x9a, AUTOPTRH1);
SFR_REG(0x9b, AUTOPTRL1);
SFR_REG(0x9d, AUTOPTRH2);
SFR_REG(0x9e, AUTOPTRL2);
SFR_REG(0xa0, IOC);
  SFR_BIT(0xa0+0, IOC_0_b);
  SFR_BIT(0xa0+1, IOC_1_b);
  SFR_BIT(0xa0+2, IOC_2_b);
  SFR_BIT(0xa0+3, IOC_3_b);
  SFR_BIT(0xa0+4, IOC_4_b);
  SFR_BIT(0xa0+5, IOC_5_b);
  SFR_BIT(0xa0+6, IOC_6_b);
  SFR_BIT(0xa0+7, IOC_7_b);
SFR_REG(0xa1, INT2CLR);
SFR_REG(0xa2, INT4CLR);
SFR_REG(0xa8, IE);
  SFR_BIT(0xa8+0, IE_EX0_b);
  SFR_BIT(0xa8+1, IE_ET0_b);
  SFR_BIT(0xa8+2, IE_EX1_b);
  SFR_BIT(0xa8+3, IE_ET1_b);
  SFR_BIT(0xa8+4, IE_ES0_b);
  SFR_BIT(0xa8+5, IE_ET2_b);
  SFR_BIT(0xa8+6, IE_ES1_b);
  SFR_BIT(0xa8+7, IE_EA_b);
SFR_REG(0xaa, EP2468STAT);
  SFR_BIT(0xaa+0, EP2468STAT_EP2E_b);
  SFR_BIT(0xaa+1, EP2468STAT_EP2F_b);
  SFR_BIT(0xaa+2, EP2468STAT_EP4E_b);
  SFR_BIT(0xaa+3, EP2468STAT_EP4F_b);
  SFR_BIT(0xaa+4, EP2468STAT_EP6E_b);
  SFR_BIT(0xaa+5, EP2468STAT_EP6F_b);
  SFR_BIT(0xaa+6, EP2468STAT_EP8E_b);
  SFR_BIT(0xaa+7, EP2468STAT_EP8F_b);
SFR_REG(0xab, EP24FIFOFLGS);
  SFR_BIT(0xab+0, EP24FIFOFLGS_EP2FF_b);
  SFR_BIT(0xab+1, EP24FIFOFLGS_EP2EF_b);
  SFR_BIT(0xab+2, EP24FIFOFLGS_EP2PF_b);
  SFR_BIT(0xab+3, EP24FIFOFLGS_EP4FF_b);
  SFR_BIT(0xab+4, EP24FIFOFLGS_EP4EF_b);
  SFR_BIT(0xab+5, EP24FIFOFLGS_EP4PF_b);
SFR_REG(0xac, EP68FIFOFLGS);
  SFR_BIT(0xac+0, EP68FIFOFLGS_EP6FF_b);
  SFR_BIT(0xac+1, EP68FIFOFLGS_EP6EF_b);
  SFR_BIT(0xac+2, EP68FIFOFLGS_EP6PF_b);
  SFR_BIT(0xac+3, EP68FIFOFLGS_EP8FF_b);
  SFR_BIT(0xac+4, EP68FIFOFLGS_EP8EF_b);
  SFR_BIT(0xac+5, EP68FIFOFLGS_EP8PF_b);
SFR_REG(0xaf, AUTOPTRSETUP);
  SFR_BIT(0xaf+0, AUTOPTRSETUP_APTREN_b);
  SFR_BIT(0xaf+1, AUTOPTRSETUP_APTR1INC_b);
  SFR_BIT(0xaf+2, AUTOPTRSETUP_APTR2INC_b);
SFR_REG(0xb0, IOD);
  SFR_BIT(0xb0+0, IOD_0_b);
  SFR_BIT(0xb0+1, IOD_1_b);
  SFR_BIT(0xb0+2, IOD_2_b);
  SFR_BIT(0xb0+3, IOD_3_b);
  SFR_BIT(0xb0+4, IOD_4_b);
  SFR_BIT(0xb0+5, IOD_5_b);
  SFR_BIT(0xb0+6, IOD_6_b);
  SFR_BIT(0xb0+7, IOD_7_b);
SFR_REG(0xb1, IOE);
  SFR_BIT(0xb1+0, IOE_0_b);
  SFR_BIT(0xb1+1, IOE_1_b);
  SFR_BIT(0xb1+2, IOE_2_b);
  SFR_BIT(0xb1+3, IOE_3_b);
  SFR_BIT(0xb1+4, IOE_4_b);
  SFR_BIT(0xb1+5, IOE_5_b);
  SFR_BIT(0xb1+6, IOE_6_b);
  SFR_BIT(0xb1+7, IOE_7_b);
SFR_REG(0xb2, OEA);
  SFR_BIT(0xb2+0, OEA_0_b);
  SFR_BIT(0xb2+1, OEA_1_b);
  SFR_BIT(0xb2+2, OEA_2_b);
  SFR_BIT(0xb2+3, OEA_3_b);
  SFR_BIT(0xb2+4, OEA_4_b);
  SFR_BIT(0xb2+5, OEA_5_b);
  SFR_BIT(0xb2+6, OEA_6_b);
  SFR_BIT(0xb2+7, OEA_7_b);
SFR_REG(0xb3, OEB);
  SFR_BIT(0xb3+0, OEB_0_b);
  SFR_BIT(0xb3+1, OEB_1_b);
  SFR_BIT(0xb3+2, OEB_2_b);
  SFR_BIT(0xb3+3, OEB_3_b);
  SFR_BIT(0xb3+4, OEB_4_b);
  SFR_BIT(0xb3+5, OEB_5_b);
  SFR_BIT(0xb3+6, OEB_6_b);
  SFR_BIT(0xb3+7, OEB_7_b);
SFR_REG(0xb4, OEC);
  SFR_BIT(0xb4+0, OEC_0_b);
  SFR_BIT(0xb4+1, OEC_1_b);
  SFR_BIT(0xb4+2, OEC_2_b);
  SFR_BIT(0xb4+3, OEC_3_b);
  SFR_BIT(0xb4+4, OEC_4_b);
  SFR_BIT(0xb4+5, OEC_5_b);
  SFR_BIT(0xb4+6, OEC_6_b);
  SFR_BIT(0xb4+7, OEC_7_b);
SFR_REG(0xb5, OED);
  SFR_BIT(0xb5+0, OED_0_b);
  SFR_BIT(0xb5+1, OED_1_b);
  SFR_BIT(0xb5+2, OED_2_b);
  SFR_BIT(0xb5+3, OED_3_b);
  SFR_BIT(0xb5+4, OED_4_b);
  SFR_BIT(0xb5+5, OED_5_b);
  SFR_BIT(0xb5+6, OED_6_b);
  SFR_BIT(0xb5+7, OED_7_b);
SFR_REG(0xb6, OEE);
  SFR_BIT(0xb6+0, OEE_0_b);
  SFR_BIT(0xb6+1, OEE_1_b);
  SFR_BIT(0xb6+2, OEE_2_b);
  SFR_BIT(0xb6+3, OEE_3_b);
  SFR_BIT(0xb6+4, OEE_4_b);
  SFR_BIT(0xb6+5, OEE_5_b);
  SFR_BIT(0xb6+6, OEE_6_b);
  SFR_BIT(0xb6+7, OEE_7_b);
SFR_REG(0xb8, IP);
  SFR_BIT(0xb8+0, IP_PX0);
  SFR_BIT(0xb8+1, IP_PT0);
  SFR_BIT(0xb8+2, IP_PX1);
  SFR_BIT(0xb8+3, IP_PT1);
  SFR_BIT(0xb8+4, IP_PS0);
  SFR_BIT(0xb8+5, IP_PT2);
  SFR_BIT(0xb8+6, IP_PS1);
SFR_REG(0xba, EP01STAT);
  SFR_BIT(0xba+0, EP01STAT_EP0BSY_b);
  SFR_BIT(0xba+1, EP01STAT_EP1OUTBSY_b);
  SFR_BIT(0xba+2, EP01STAT_EP1INBSY_b);
SFR_REG(0xbb, GPIFTRIG);
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

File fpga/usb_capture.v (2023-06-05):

// SPDX-License-Identifier: BSD-3-Clause
// Copyright (c) 2023, Alex Taradov <alex@taradov.com>. All rights reserved.

`timescale 1ns / 1ps

module usb_capture (
  input         reset_i,

  input         usb_clk_i,
  output        usb_stp_o,
  input         usb_dir_i,
  input         usb_nxt_i,
  inout   [7:0] usb_d_io,

  input   [1:0] usb_dm_i,
  input   [1:0] usb_dp_i,

  output  [7:0] int_data_o,
  output        int_valid_o,
  input         int_ack_i,

  input         ctrl_enable_i,
  input   [1:0] ctrl_speed_i,

  input         trigger_i
);

//-----------------------------------------------------------------------------
localparam PTR_WIDTH = 13;
localparam FIFO_SIZE = 1 << PTR_WIDTH;

localparam
  DATA_HEADER_SIZE   = 3'd7,
  STATUS_HEADER_SIZE = 3'd4;

localparam
  USB_SPEED_LS      = 2'b00,
  USB_SPEED_FS      = 2'b01,
  USB_SPEED_HS      = 2'b10,
  USB_SPEED_AUTO    = 2'b11,
  USB_SPEED_UNKNOWN = 2'b11;

//-----------------------------------------------------------------------------
reg utmi_rx_active_r = 1'b0;

wire utmi_rx_active_w;

always @(posedge usb_clk_i) begin
  utmi_rx_active_r <= utmi_rx_active_w;
end

wire rx_start_w = (!utmi_rx_active_r && utmi_rx_active_w);
wire rx_stop_w  = (utmi_rx_active_r && !utmi_rx_active_w);

//-----------------------------------------------------------------------------
wire [1:0] speed_detect_w;

speed_detect speed_detect_inst (
  .clk_i       (usb_clk_i),
  .dm_i        (usb_dm_i),
  .dp_i        (usb_dp_i),
  .vbus_i      (utmi_vbus_w[1]),
  .rx_active_i (utmi_rx_active_r),
  .speed_o     (speed_detect_w)
);

wire [1:0] auto_speed_w = (speed_detect_w == USB_SPEED_UNKNOWN) ? USB_SPEED_HS : speed_detect_w;
wire [1:0] speed_w = (ctrl_speed_i == USB_SPEED_AUTO) ? auto_speed_w : ctrl_speed_i;

wire [1:0] utmi_xcvrselect_w =
  (speed_w == USB_SPEED_LS) ? 2'b10 :
  (speed_w == USB_SPEED_FS) ? 2'b01 : 2'b00;

wire utmi_termselect_w = (speed_w == USB_SPEED_HS) ? 1'b0 : 1'b1;

//-----------------------------------------------------------------------------
wire [7:0] utmi_rx_data_w;
wire       utmi_rx_valid_w;
wire       utmi_rx_error_w;
wire [1:0] utmi_vbus_w;

usb_phy usb_phy_inst (
  .ulpi_clk_i        (usb_clk_i),
  .ulpi_data_io      (usb_d_io),
  .ulpi_dir_i        (usb_dir_i),
  .ulpi_nxt_i        (usb_nxt_i),
  .ulpi_stp_o        (usb_stp_o),

  .utmi_rx_data_o    (utmi_rx_data_w),
  .utmi_rx_active_o  (utmi_rx_active_w),
  .utmi_rx_valid_o   (utmi_rx_valid_w),
  .utmi_rx_error_o   (utmi_rx_error_w),
  .utmi_tx_data_i    (8'h00),
  .utmi_tx_valid_i   (1'b0),
  .utmi_tx_ready_o   (),

  .utmi_xcvrselect_i (utmi_xcvrselect_w),
  .utmi_termselect_i (utmi_termselect_w),
  .utmi_opmode_i     (2'b01),
  .utmi_dppulldown_i (1'b0),
  .utmi_dmpulldown_i (1'b0),
  .utmi_linestate_o  (),
  .utmi_vbus_o       (utmi_vbus_w)
);

//-----------------------------------------------------------------------------
localparam
  ST_IDLE     = 3'd0,
  ST_DATA     = 3'd1,
  ST_DATA_OVF = 3'd2,
  ST_HEADER   = 3'd3,
  ST_OVERFLOW = 3'd4;

reg  [2:0] state_r;
reg [10:0] data_size_r;
reg        data_error_r;
reg        overflow_r;
reg        pid_rx_r;
reg        pid_ok_r;
reg  [3:0] pid_r;

always @(posedge usb_clk_i) begin
  if (reset_i) begin
    data_size_r  <= STATUS_HEADER_SIZE;
    data_error_r <= 1'b0;
    overflow_r   <= 1'b0;
    pid_rx_r     <= 1'b0;
    pid_ok_r     <= 1'b0;
    pid_r        <= 4'h0;
    state_r      <= ST_IDLE;
  end else case (state_r)
    ST_IDLE: begin
      data_size_r <= STATUS_HEADER_SIZE;

      if (rx_start_w && ctrl_enable_i) begin
        data_size_r  <= DATA_HEADER_SIZE;
        data_error_r <= 1'b0;
        pid_rx_r     <= 1'b0;
        state_r      <= fifo_ready_w ? ST_DATA : ST_OVERFLOW;
      end
    end

    ST_DATA: begin
      if (!utmi_rx_active_w) begin
        state_r <= ST_HEADER;
      end else if (fifo_overflow_w && utmi_rx_valid_w) begin
        state_r <= ST_OVERFLOW;
      end else if (data_size_r == 11'd1280) begin
        state_r <= ST_DATA_OVF;
      end else if (utmi_rx_valid_w)
        data_size_r <= data_size_r + 11'd1;

      if (utmi_rx_valid_w && !pid_rx_r) begin
        pid_rx_r <= 1'b1;
        pid_ok_r <= (utmi_rx_data_w[3:0] == ~utmi_rx_data_w[7:4]);
        pid_r    <= utmi_rx_data_w[3:0];
      end

      if (utmi_rx_error_w)
        data_error_r <= 1'b1;
    end

    ST_DATA_OVF: begin
      if (!utmi_rx_active_w) begin
        state_r <= ST_HEADER;
      end
    end

    ST_HEADER: begin
      if (commit_data_w) begin
        overflow_r <= 1'b0;
        state_r <= ST_IDLE;
      end
    end

    ST_OVERFLOW: begin
      overflow_r <= 1'b1;

      if (!utmi_rx_active_w)
        state_r <= ST_IDLE;
    end
  endcase
end

//-----------------------------------------------------------------------------
// Switching hysteresis because comparators are not symmetric
reg dp_r;
reg dm_r;

always @(posedge usb_clk_i) begin
  dp_r <= dp_r ? usb_dp_i[1] : (usb_dp_i == 2'd3);
  dm_r <= dm_r ? usb_dm_i[1] : (usb_dm_i == 2'd3);
end

//-----------------------------------------------------------------------------
localparam
  SYNC_ST_IDLE     = 2'd0,
  SYNC_ST_COUNT    = 2'd1,
  SYNC_ST_WAIT     = 2'd2,
  SYNC_ST_DETECTED = 2'd3;

localparam SYNC_COUNT_TIME   = 8'd30;
localparam SYNC_WAIT_TIME    = 8'd20;
localparam SYNC_DETECT_TIME  = 8'd160;
localparam SYNC_DETECT_COUNT = 3'd6;

reg [1:0] sync_state_r;
reg [7:0] sync_cnt_r;
reg [2:0] sync_bit_r;

wire ls_j_w = (!dp_r &&  dm_r);
wire ls_k_w = ( dp_r && !dm_r);
wire sync_cond_w = sync_bit_r[0] ? ls_j_w : ls_k_w;
wire sync_detected_w = (sync_state_r == SYNC_ST_DETECTED);

always @(posedge usb_clk_i) begin
  if (reset_i || utmi_rx_active_w || speed_w != USB_SPEED_LS) begin
    sync_state_r <= SYNC_ST_IDLE;
  end else case (sync_state_r)
    SYNC_ST_IDLE: begin
      sync_cnt_r <= 8'd0;
      sync_bit_r <= 3'd0;

      if (ls_k_w)
        sync_state_r <= SYNC_ST_COUNT;
    end

    SYNC_ST_COUNT: begin
      if (!sync_cond_w)
        sync_state_r <= SYNC_ST_IDLE;
      else if (sync_cnt_r == SYNC_COUNT_TIME) begin
        sync_cnt_r <= 8'd0;
        sync_bit_r <= sync_bit_r + 3'd1;

        if (sync_bit_r == SYNC_DETECT_COUNT)
          sync_state_r <= SYNC_ST_DETECTED;
        else
          sync_state_r <= SYNC_ST_WAIT;
      end else
        sync_cnt_r <= sync_cnt_r + 8'd1;
    end

    SYNC_ST_WAIT: begin
      if (sync_cond_w) begin
        sync_cnt_r <= 8'd0;
        sync_state_r <= SYNC_ST_COUNT;
      end else if (sync_cnt_r == SYNC_WAIT_TIME)
        sync_state_r <= SYNC_ST_IDLE;
      else
        sync_cnt_r <= sync_cnt_r + 8'd1;
    end

    SYNC_ST_DETECTED: begin
      if (sync_cnt_r == SYNC_DETECT_TIME)
        sync_state_r <= SYNC_ST_IDLE;
      else
        sync_cnt_r <= sync_cnt_r + 8'd1;
    end
  endcase
end

//-----------------------------------------------------------------------------
reg trigger_r;
reg [5:0] trigger_filter_r;
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

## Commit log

2023-06-05 Added all the files
    [host-usb.kicad_sch, target-usb.kicad_sch, usb-sniffer-v6-Case.stl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]
2023-06-16 Added EEPROM part name
    [host-usb.kicad_sch, target-usb.kicad_sch, usb-sniffer.kicad_pcb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]
2023-06-16 Fixed resistor value
    [usb-sniffer.kicad_pcb, usb-sniffer.kicad_sch]
2023-06-16 Fixed C9 symbol reference
    [usb-sniffer.kicad_sch]
2023-06-17 Added BOM
    [usb-sniffer-bom.csv]
2023-07-15 Fixed possible buffer overflows
    [usb.c]
2024-05-16 KiCad files updated
2024-05-16 Updated extcap paths for the latest Wireshark version
2025-02-25 Added support for using multiple sniffer boards
    Allows users to open multiple Wireshark instances, each with a connection to its own usb-sniffer board.
2025-03-06 Increased frame folding buffer size
